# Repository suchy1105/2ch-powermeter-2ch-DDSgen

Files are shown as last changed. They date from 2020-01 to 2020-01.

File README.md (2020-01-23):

# 2ch-powermeter-2ch-DDSgen
2 channel power meter with 2 channel DDS generator with few interfaces 

It is a part of my engeeniering thesis, made in AltiumDesigner, based on STM32F4 reconfigurable with DDS generator AD9851 and logaritmic amplifiler AD8307.

Code(C language) was compile in SystemWorkbench(eclipse), with using CubeMX. The program was upload by STM32CubeProgrammer.
KS

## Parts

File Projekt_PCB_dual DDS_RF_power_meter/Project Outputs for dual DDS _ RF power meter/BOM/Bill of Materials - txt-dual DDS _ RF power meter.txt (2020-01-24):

Comment	Description	Designator	Footprint	LibRef	Manufacturer	Manufacturer Part Number	Manufacturer1 ComponentHeight	Manufacturer1 Example	Manufacturer1 Part Number	Part Description	Part Number	Quantity

"Device"	""	"IC11_U_POWERMES_1, IC11_U_POWERMES_2"	"SOIC127P600X175-8N"	"AD8307AR"	""	""	""	""	""	""	""	"2"
"IRF7389"	""	"Q4, Q5"	"SO-8"	"IRF7389"	""	""	""	""	""	""	""	"2"
"IS42S16"	"SDRAM 64m 200mhz 54tsop"	"IC1"	"TSOP-54"	"IS42S16"	""	""	""	""	""	""	""	"1"
"LAN8742A-CZ-TR"	"LAN8742A-CZ-TR - Small Footprint RMII 10/100 Ethernet, Transceiver with HP Auto-MDIX and flexPWR Technology SQFN-24"	"U2"	"QFN50P400X400X80-25N-S225"	"LAN8742A-CZ-TR"	""	""	""	""	""	""	""	"1"
"LEDRA3010-GYW120"	"LED (Maritex)"	"LED1, LED2, LED3, LED4, LED5"	"LED_KPA3010_G"	"LED_SMD_90deg_G"	""	""	""	""	""	""	""	"5"
"MCP1525T-I/TT"	"2.5 voltage reference"	"IC4"	"SOT95P251X112-3N"	"REF_MCP1525"	""	""	""	""	""	""	""	"1"
"STM809SWX6F"	"2.93V  Reset circuit"	"IC3"	"SOT95P229X119-3N"	"VMON_STM809"	""	""	""	""	""	""	""	"1"
"TC4428A"	"MOSFET Driver"	"IC5, IC6"	"SO-8"	"DRV_TC4428A"	""	""	""	""	""	""	""	"2"
"Header 34"	"Connector 34 Male"	"J3"	"3M_N2534-6002RB"	"3M_N2534-6002RB"	"3M"	"N2534-6002RB"	""	""	""	"34 Contacts - Straight .100'' x .100'' Low Profile Four-Wall Header, 2500 Series"	"3M_N2534-6002RB"	"1"
"32.768KHZ"	"Quartz Crystal"	"Q3"	"XTAL_ABRACON_ABS09"	"XTAL_32.768KHZ_ABRACON_ABS09-32.768KHZ-T"	"ABRACON"	"ABS09-32.768KHZ-T"	""	""	""	"Tolerance: ±20ppm, Stability: ±5ppm, -40°C to +85°C, 12.5pF, SMD Low Profile Crystal, ABS09 Series"	"XTAL_32.768KHZ_ABRACON_ABS09-32.768KHZ-T"	"1"
"MicroUSB-B"	"MicroUSB-B-SMT"	"J5, J7"	"USB-Micro-B-RA-SMD-PiP"	"USB-Micro-B-RA-SMD-PiP"	"Allen Creations Corp."	"AJU55-BS2111-L"	""	""	""	""	"USB-Micro-B-RA-SMD-PiP"	"2"
"AD9851BRSZ"	"CMOS 180MHz DDS/DAC Synthesizer"	"IC10_U_Generator_1, IC10_U_Generator_2"	"SOP65P780X200-28N"	"AD9851BRSZ"	"ANALOG DEVICES"	"AD9851BRSZ"	""	""	""	"CMOS 180MHz DDS/DAC Synthesizer, 10-Bit"	"AD9851BRSZ"	"2"
"AT24C64AN-10SU-1.8"	"64K (8192 x 8), Two-Wire Serial EEPROM"	"IC7"	"SOIC127P600X175-8N"	"AT24C64AN-10SU-1.8"	"ATMEL"	"AT24C64AN-10SU-1.8"	""	""	""	"1.8V, 64K (8192 x 8), Two-Wire Serial EEPROM"	"AT24C64AN-10SU-1.8"	"1"
"microSD"	"Connector MicroSD 8 Pin + Switch"	"J2"	"ATTEND_112A-TAAR-R03"	"ATTEND_112A-TAAR-R03"	"ATTEND"	"112A-TAAR-R03"	""	""	""	"MicroSD Socket, Push-Push Type"	"ATTEND_112A-TAAR-R03"	"1"
"51"	"Resistor - 5%"	"R15, R22, R23, R24"	"RESC6331X80N"	"R2512_51R_5%_2W_200PPM_BOURNS_CRM2512"	"BOURNS"	"CRM2512-JW-510ELF"	""	""	""	"Pulse Resistant Power Thick Film Chip Resistor"	"R2512_51R_5%_2W_200PPM_BOURNS_CRM2512"	"4"
"SMAJ5.0A"	"Transient Voltage Suppressor Diode (Uni-Directional)"	"D3"	"DIOM5226X262N"	"SMAJ5.0A"	"BOURNS"	"SMAJ5.0A"	""	""	""	"Surface Mount Uni-directional Transient Voltage Suppressor Diode"	"SMAJ5.0A"	"1"
"Jack"	"12V /  5A, 2.1mm Diameter Pin, DC Power Socket With  Switch. DC10A Type"	"J6"	"CLIFF_FC68148(DC-10A)"	"CLIFF_FC68148(DC-10A)"	"CLIFF ELECTRONIC COMPONENTS"	"FC68148 (DC-10A)"	""	""	""	"12V/5A, 2.1mm Diameter Pin, DC Power Socket With  Switch (DC10A Type)"	"CLIFF_FC68148(DC-10A)"	"1"
"Switch"	"4 Ways SPST DIP Switch"	"SW1"	"SW_CTS_219-4MST"	"SW_CTS_219-4MST"	"CTS ELECTROCOMPONENTS"	"219-4MST"	""	""	""	"4 Ways, Pitch 2.54mm, SPST DIP Switch, Rating 100mA 50VDC"	"SW_CTS_219-4MST"	"1"
"25MHz"	"Crystal 4 pins 1=XTAL Control 2=GND3=XTAL 4=GND"	"Q1"	"XTAL_EPSON_TSX-3225"	"XTAL_25MHZ_EPSON_TSX-3225 25.0000MF10Z-AC"	"EPSON"	"TSX-3225 25.0000MF10Z-AC"	""	""	""	"Tolerance ±10 ppm,  Stability:± 10ppm, -20°C to 75°C, 9pF, Surface Mount Quartz Crystal, TX-3225 Series"	"XTAL_25MHZ_EPSON_TSX-3225 25.0000MF10Z-AC"	"1"
"BAT54C"	"Dual Common Cathode Schottky Diodes"	"D4, D10"	"SOT95P240X130-3N"	"BAT54C"	"FAIRCHILD SEMICONDUCTOR"	"BAT54C"	""	""	""	"Dual Common Cathode Small Signal Schottky Diode"	"BAT54C"	"2"
"0"	"Resistor"	"R107_U_Generator_1, R107_U_Generator_2, R108_U_Generator_1, R108_U_Generator_2, R110_U_POWERMES_1, R110_U_POWERMES_2"	"RESC1608X55N"	"R0603_0R_JUMPER"	"GENERIC"	"R0603_0R_JUMPER"	"0.55mm"	"NIC COMPONENT"	"NRC06Z0"	"1A (0.05R Max DC Resistance) Zero Ohm Jumper"	"R0603_0R_JUMPER"	"6"
"0"	"Resistor"	"R43, R62, R63, R64"	"RESC1005X40N"	"R0402_0R_JUMPER"	"GENERIC"	"R0402_0R_JUMPER"	"0.4mm"	"YAGEO PHYCOMP"	"232270591001L"	"1A (0.05R Max DC Resistance) Zero Ohm Jumper"	"R0402_0R_JUMPER"	"4"
"100nF"	"Non-polarised capacitor"	"C1, C2, C3, C4, C5, C6, C7, C8, C9, C10, C11, C12, C13, C14, C15, C16, C17, C18, C19, C20, C21, C22, C25, C28, C29, C30, C32, C34, C38, C39, C40, C49, C50, C51, C54, C61, C64, C65, C66, C67"	"CAPC1005X55N"	"CC0402_100NF_16V_10%_X5R"	"GENERIC"	"CC0402_100NF_16V_10%_X5R"	"0.55mm"	"MURATA"	"GRM155R61C104KA88D"	"SMD Multilayer Chip Ceramic Capacitor"	"CC0402_100NF_16V_10%_X5R"	"40"
"100nF"	"Non-polarised capacitor"	"C33, C35"	"CAPC1608X87N"	"CC0603_100NF_50V_10%_X7R"	"GENERIC"	"CC0603_100NF_50V_10%_X7R"	"0.87mm"	"PHYCOMP"	"223858615649"	"SMD Multilayer Chip Ceramic Capacitor"	"CC0603_100NF_50V_10%_X7R"	"2"
"100nF"	"Non-polarised capacitor"	"C59_U_Generator_1, C59_U_Generator_2, C71_U_Generator_1, C71_U_Generator_2, C72_U_Generator_1, C72_U_Generator_2, C73_U_Generator_1, C73_U_Generator_2, C74_U_Generator_1, C74_U_Generator_2, C76_U_POWERMES_1, C76_U_POWERMES_2"	"CAPC0603X33N"	"CC0201_100NF_6.3V_10%_X5R"	"GENERIC"	"CC0201_100NF_6.3V_10%_X5R"	"0.33mm"	"AVX"	"02016D104KAT2A"	"SMD Multilayer Chip Ceramic Capacitor"	"CC0201_100NF_6.3V_10%_X5R"	"12"
"10k"	"Resistor - 1%"	"R16, R17, R18, R19, R20, R21, R25, R28, R29, R30, R31, R32, R33, R34, R35, R36, R44, R47, R48, R49, R50, R51, R57, R58, R59, R93, R94, R95, R96, R100_U_Generator_1, R100_U_Generator_2"	"RESC1005X40N"	"R0402_10K_1%_0.0625W_100PPM"	"GENERIC"	"R0402_10K_1%_0.0625W_100PPM"	"0.4mm"	"YAGEO PHYCOMP"	"232270671003L"	"General Purpose Thick Film Chip Resistor"	"R0402_10K_1%_0.0625W_100PPM"	"31"
"10nF"	"Non-polarised capacitor"	"C58"	"CAPC1005X55N"	"CC0402_10NF_16V_10%_X7R"	"GENERIC"	"CC0402_10NF_16V_10%_X7R"	"0.55mm"	"PHYCOMP"	"223878715636"	"SMD Multilayer Chip Ceramic Capacitor"	"CC0402_10NF_16V_10%_X7R"	"1"
"10uF"	"Non-polarised capacitor"	"C31"	"CAPC2012X135N"	"CC0805_10UF_16V_10%_X5R"	"GENERIC"	"CC0805_10UF_16V_10%_X5R"	"1.4mm"	"KEMET"	"C0805C106K4PAC"	"SMD Multilayer Chip Ceramic Capacitor"	"CC0805_10UF_16V_10%_X5R"	"1"
"10uF"	"Non-polarised capacitor"	"C47, C48"	"CAPC3216X140N"	"CC1206_10UF_16V_10%_X7R"	"GENERIC"	"CC1206_10uF_16V_10%_X7R"	"1.8mm"	"KEMET"	"C1206C106K4RAC"	"SMD Multilayer Chip Ceramic Capacitor"	"CC1206_10UF_16V_10%_X7R"	"2"
"10uF"	"Non-polarised capacitor"	"C75_U_Generator_1, C75_U_Generator_2"	"CAPC1608X80N"	"CC0603_10UF_10V_10%_X5R"	"GENERIC"	"CC0603_10UF_10V_10%_X5R"	"0.8mm"	"MURATA"	"GRM188R61A106KE69D"	"SMD Multilayer Chip Ceramic Capacitor"	"CC0603_10UF_10V_10%_X5R"	"2"
"12pF"	"Non-polarised capacitor"	"C36, C37, C52, C55"	"CAPC1005X55N"	"CC0402_12PF_50V_5%_C0G"	"GENERIC"	"CC0402_12PF_50V_5%_C0G"	"0.55mm"	"KEMET"	"C0402C120J5GACTU"	"SMD Multilayer Chip Ceramic Capacitor"	"CC0402_12PF_50V_5%_C0G"	"4"
"150pF"	"Non-polarised capacitor"	"C46"	"CAPC1005X55N"	"CC0402_150PF_50V_5%_C0G"	"GENERIC"	"CC0402_150PF_50V_5%_C0G"	"0.55mm"	"KEMET"	"C0402C151J5GACTU"	"SMD Multilayer Chip Ceramic Capacitor"	"CC0402_150PF_50V_5%_C0G"	"1"
"18pF"	"Non-polarised capacitor"	"C26, C27"	"CAPC1005X55N"	"CC0402_18PF_50V_5%_C0G"	"GENERIC"	"CC0402_18PF_50V_5%_C0G"	"0.55mm"	"KEMET"	"C0402C180J5GACTU"	"SMD Multilayer Chip Ceramic Capacitor"	"CC0402_18PF_50V_5%_C0G"	"2"
"1k"	"Resistor - 1%"	"R102_U_Generator_1, R102_U_Generator_2, R103_U_Generator_1, R103_U_Generator_2"	"RESC1005X40N"	"R0402_1K_1%_0.0625W_100PPM"	"GENERIC"	"R0402_1K_1%_0.0625W_100PPM"	"0.4mm"	"YAGEO PHYCOMP"	"232270671002L"	"General Purpose Thick Film Chip Resistor"	"R0402_1K_1%_0.0625W_100PPM"	"4"
"1k5"	"Resistor - 1%"	"R5"	"RESC1005X40N"	"R0402_1K5_1%_0.0625W_100PPM"	"GENERIC"	"R0402_1K5_1%_0.0625W_100PPM"	"0.4mm"	"YAGEO PHYCOMP"	"232270671502L"	"General Purpose Thick Film Chip Resistor"	"R0402_1K5_1%_0.0625W_100PPM"	"1"
"1uF"	"Non-polarised capacitor"	"C24, C43"	"CAPC1005X55N"	"CC0402_1UF_16V_10%_X5R"	"GENERIC"	"CC0402_1UF_16V_10%_X5R"	"0.55mm"	"TDK"	"C1005X5R1C105KT"	"SMD Multilayer Chip Ceramic Capacitor"	"CC0402_1UF_16V_10%_X5R"	"2"
"2.2uF"	"Non-polarised capacitor"	"C56, C57"	"CAPC1608X87N"	"CC0603_2.2UF_16V_10%_X5R"	"GENERIC"	"CC0603_2.2UF_16V_10%_X5R"	"0.9mm"	"YAGEO"	"CC0603KRX5R7BB225"	"SMD Multilayer Chip Ceramic Capacitor"	"CC0603_2.2UF_16V_10%_X5R"	"2"
"21k"	"Resistor - 0.1%"	"R12"	"RESC1608X55N"	"R0603_21K_0.1%_0.063W_10PPM"	"GENERIC"	"R0603_21K_0.1%_0.063W_10PPM"	"0.5mm"	"TYCO HOLSWORTHY"	"RN73C1J21KBTDF"	"Thin Film Chip Resistor"	"R0603_21K_0.1%_0.063W_10PPM"	"1"
"220pF"	"Non-polarised capacitor"	"C42_U_POWERMES_1, C42_U_POWERMES_2, C53_U_POWERMES_1, C53_U_POWERMES_2"	"CAPC1005X55N"	"CC0402_220PF_50V_5%_C0G"	"GENERIC"	"CC0402_220PF_50V_5%_C0G"	"0.55mm"	"KEMET"	"C0402C221J5GACTU"	"SMD Multilayer Chip Ceramic Capacitor"	"CC0402_220PF_50V_5%_C0G"	"4"
"22uF"	"Non-polarised capacitor"	"C60, C62, C63"	"CAPC2012X135N"	"CC0805_22UF_16V_10%_X5R"	"GENERIC"	"CC0805_22UF_16V_10%_X5R"	"1.35mm"	"TDK"	"C2012X5R1C226KT"	"SMD Multilayer Chip Ceramic Capacitor"	"CC0805_22UF_16V_10%_X5R"	"3"
"24"	"Resistor - 1%"	"R98_U_Generator_1, R98_U_Generator_2"	"RESC1005X40N"	"R0402_24R_1%_0.0625W_100PPM"	"GENERIC"	"R0402_24R_1%_0.0625W_100PPM"	"0.4mm"	"YAGEO PHYCOMP"	"232270672409L"	"General Purpose Thick Film Chip Resistor"	"R0402_24R_1%_0.0625W_100PPM"	"2"
"24k"	"Resistor - 1%"	"R45"	"RESC1005X40N"	"R0402_24K_1%_0.0625W_100PPM"	"GENERIC"	"R0402_24K_1%_0.0625W_100PPM"	"0.4mm"	"YAGEO PHYCOMP"	"232270672403L"	"General Purpose Thick Film Chip Resistor"	"R0402_24K_1%_0.0625W_100PPM"	"1"
"24k9"	"Resistor - 0.1%"	"R52"	"RESC1608X55N"	"R0603_24K9_0.1%_0.063W_10PPM"	"GENERIC"	"R0603_24K9_0.1%_0.063W_10PPM"	"0.5mm"	"TYCO HOLSWORTHY"	"RN73C1J24K9BTDF"	"Thin Film Chip Resistor"	"R0603_24K9_0.1%_0.063W_10PPM"	"1"
"33"	"Resistor - 1%"	"R10, R11, R13, R97"	"RESC1005X40N"	"R0402_33R_1%_0.0625W_100PPM"	"GENERIC"	"R0402_33R_1%_0.0625W_100PPM"	"0.4mm"	"YAGEO PHYCOMP"	"232270673309L"	"General Purpose Thick Film Chip Resistor"	"R0402_33R_1%_0.0625W_100PPM"	"4"
"3k92"	"Resistor - 0.1%"	"R101_U_Generator_1, R101_U_Generator_2"	"RESC1608X55N"	"R0603_3K92_0.1%_0.063W_10PPM"	"GENERIC"	"R0603_3K92_0.1%_0.063W_10PPM"	"0.5mm"	"TYCO HOLSWORTHY"	"RN73C1J3K92BTDF"	"Thin Film Chip Resistor"	"R0603_3K92_0.1%_0.063W_10PPM"	"2"
"47"	"Resistor - 1%"	"R26, R27, R37, R38, R39, R40, R41, R55, R56, R60, R61, R65, R66, R67, R68, R69, R70, R71, R72, R73, R74, R75, R76, R77, R78, R79, R80, R81, R82, R83, R84, R85, R86, R87, R88, R89, R90, R91, R92"	"RESC1005X40N"	"R0402_47R_1%_0.0625W_100PPM"	"GENERIC"	"R0402_47R_1%_0.0625W_100PPM"	"0.4mm"	"YAGEO PHYCOMP"	"232270674709L"	"General Purpose Thick Film Chip Resistor"	"R0402_47R_1%_0.0625W_100PPM"	"39"
"470pF"	"Non-polarised capacitor"	"C23"	"CAPC1005X55N"	"CC0402_470PF_50V_10%_X7R"	"GENERIC"	"CC0402_470PF_50V_10%_X7R"	"0.55mm"	"PHYCOMP"	"223858715618"	"SMD Multilayer Chip Ceramic Capacitor"	"CC0402_470PF_50V_10%_X7R"	"1"
"47k"	"Resistor - 1%"	"R46"	"RESC1005X40N"	"R0402_47K_1%_0.0625W_100PPM"	"GENERIC"	"R0402_47K_1%_0.0625W_100PPM"	"0.4mm"	"YAGEO PHYCOMP"	"232270675103L"	"General Purpose Thick Film Chip Resistor"	"R0402_47K_1%_0.0625W_100PPM"	"1"
"49R9"	"Resistor - 0.1%"	"R1, R2, R3, R4"	"RESC1005X35N"	"R0402_49R9_0.1%_0.063W_25PPM"	"GENERIC"	"R0402_49R9_0.1%_0.063W_25PPM"	"0.35mm"	"TE CONNECTIVITY"	"CPF0402B49R9E1"	"Thin Film Precision Resistor"	"R0402_49R9_0.1%_0.063W_25PPM"	"4"
"49R9"	"Resistor - 1%"	"R42, R99_U_Generator_1, R99_U_Generator_2"	"RESC1005X40N"	"R0402_49R9_1%_0.0625W_100PPM"	"GENERIC"	"R0402_49R9_1%_0.0625W_100PPM"	"0.4mm"	"YAGEO PHYCOMP"	"232270674999L or RC0402FR-0749R9L"	"General Purpose Thick Film Chip Resistor"	"R0402_49R9_1%_0.0625W_100PPM"	"3"
"4k7"	"Resistor - 1%"	"R6, R7, R8, R9, R14"	"RESC1005X40N"	"R0402_4K7_1%_0.0625W_100PPM"	"GENERIC"	"R0402_4K7_1%_0.0625W_100PPM"	"0.4mm"	"YAGEO PHYCOMP"	"232270674702L"	"General Purpose Thick Film Chip Resistor"	"R0402_4K7_1%_0.0625W_100PPM"	"5"
"4k99"	"Resistor - 1%"	"R54"	"RESC1608X55N"	"R0603_4K99_1%_0.063W_50PPM"	"GENERIC"	"R0603_4K99_1%_0.063W_50PPM"	"0.55mm"	"TYCO NEOHM"	"CPF0603F4K99C1"	"General Purpose Thick Film Chip Resistor"	"R0603_4K99_1%_0.063W_50PPM"	"1"
"4R7"	"Resistor - 1%"	"R109_U_POWERMES_1, R109_U_POWERMES_2"	"RESC1005X40N"	"R0402_4R7_1%_0.0625W_200PPM"	"GENERIC"	"R0402_4R7_1%_0.0625W_200PPM"	"0.4mm"	"YAGEO PHYCOMP"	"232270674708L"	"General Purpose Thick Film Chip Resistor"	"R0402_4R7_1%_0.0625W_200PPM"	"2"
"50"	"Resistor - 0.1%"	"R105, R106"	"RESC1005X35N"	"R0402_50R_0.1%_0.05W_25PPM"	"GENERIC"	"R0402_50R_0.1%_0.05W_25PPM"	"0.38mm"	"VISHAY DALE"	"FC0402E50R0BTBS"	"Thin Film Precision Resistor"	"R0402_50R_0.1%_0.05W_25PPM"	"2"
"51"	"Resistor - 1%"	"R104_U_POWERMES_1, R104_U_POWERMES_2"	"RESC1005X40N"	"R0402_51R_1%_0.0625W_100PPM"	"GENERIC"	"R0402_51R_1%_0.0625W_100PPM"	"0.4mm"	"YAGEO PHYCOMP"	"232270675109L"	"General Purpose Thick Film Chip Resistor"	"R0402_51R_1%_0.0625W_100PPM"	"2"
"6.8nF"	"Non-polarised capacitor"	"C68"	"CAPC1608X87N"	"CC0603_6.8NF_50V_5%_X7R"	"GENERIC"	"CC0603_6.8NF_50V_5%_X7R"	"0.87mm"	"PHYCOMP"	"223858615634"	"SMD Multilayer Chip Ceramic Capacitor"	"CC0603_6.8NF_50V_5%_X7R"	"1"
"7k87"	"Resistor - 0.1%"	"R53"	"RESC1608X55N"	"R0603_7K87_0.1%_0.063W_10PPM"	"GENERIC"	"R0603_7K87_0.1%_0.063W_10PPM"	"0.5mm"	"TYCO HOLSWORTHY"	"RN73C1J7K87BTDF"	"Thin Film Chip Resistor"	"R0603_7K87_0.1%_0.063W_10PPM"	"1"
"SMA"	""	"J4, J8_U_Generator_1, J8_U_Generator_2, J9_U_POWERMES_1, J9_U_POWERMES_2"	"HUBER-SUHNER_85_SMA-50-0-101/111_NE"	"HUBER-SUHNER_85_SMA-50-0-101/111_NE"	"HUBER+SUHNER"	"85_SMA-50-0-101/111_NE"	""	""	""	"SMA 50 Ohms Right Angle PCB Jack"	"HUBER-SUHNER_85_SMA-50-0-101/111_NE"	"5"
"Value"	"Battery Holder whit 2 Pin"	"BATH1"	"BATH_KEYSTONE_2998"	"BATH_KEYSTONE_2998"	"KEYSTONE"	"2998"	""	""	""	"SMD Battery Holder for SR60, SR66, SR621, LR621, MC621, V364, SC621, DR13H, D377, V13AT Buttun Cell Battery"	"BATH_KEYSTONE_2998"	"1"
"25MHz"	"Oscillator 4 pins 1=\ST 2=GND 3=OUT 4=VCC"	"OSC1"	"OSC_MICREL_2520"	"OSC_25MHZ_MICREL_DSC1001DI5-025.0000T"	"MICREL"	"DSC1001DI5-025.0000T"	""	""	""	"1.8V-3.3V, ±10ppm, 15pF,-40..85°C, HCMOS/TTL Surface Mount Low-Power Precision CMOS Oscillator (DSC1001 Series)"	"OSC_25MHZ_MICREL_DSC1001DI5-025.0000T"	"1"
"220R@100MHz"	"Inductor"	"FB1, FB2, FB3, L2"	"INDC2012X105N"	"IND0805_MURATA_BLM21PG221SN1D"	"MURATA"	"BLM21PG221SN1D"	""	""	""	"SMD EMIFIL Suppression Chip Ferrite Bead"	"IND0805_MURATA_BLM21PG221SN1D"	"4"
"90R@100MHz"	"Inductor Common Mode"	"L1, L6"	"IND_MURATA_DLW21S"	"IND_MURATA_DLW21SN900SQ2L"	"MURATA"	"DLW21SN900SQ2L"	""	""	""	"Wire Wound Common Mode Choke Coil (DLW21S Series)"	"IND_MURATA_DLW21SN900SQ2L"	"2"
"74AHC1G04GW"	"Single Inverter Buffer"	"IC8, IC9"	"SOT65P212X110-5N"	"74AHC1G04GW"	"NXP SEMICONDUCTORS"	"74AHC1G04GW"	""	""	""	"Single Inverter Buffer"	"74AHC1G04GW"	"2"
"PRTR5V0U2X"	"Ultra Low Capacitance Double Rail-to-Rail ESD Protection Diode"	"D1, D2, D6, D11"	"SOT190P230X110-4N"	"PRTR5V0U2X"	"NXP SEMICONDUCTORS"	"PRTR5V0U2X"	""	""	""	"Ultra Low Capacitance (1pF) Double Rail-to-Rail ESD Protection Diode (8kV)"	"PRTR5V0U2X"	"4"
"NCP3170ADR2G"	"Synchronous PWM Switching Converter"	"IC2"	"SOIC127P600X175-8N"	"NCP3170ADR2G"	"ON SEMICONDUCTOR"	"NCP3170ADR2G"	""	""	""	"Synchronous PWM Switching Converter"	"NCP3170ADR2G"	"1"
""	"LED Green 1C 2A"	"LD10, LD11, LD12"	"LED_OSRAM_LGL29K"	"LED_OSRAM_LG L29K-G2J1-24-Z"	"OSRAM"	"LG L29K-G2J1-24-Z"	""	""	""	"Surface Mount Green LED (0603 Case)"	"LED_OSRAM_LG L29K-G2J1-24-Z"	"3"
"100uF"	"Polarised capacitor"	"C41"	"CAPAE660X540N"	"CAE660-540_100UF_16V_20%"	"PANASONIC"	"EEEFK1C101AP"	""	""	""	"Aluminum Electrolytic SMT Capacitor"	"CAE660-540_100UF_16V_20%"	"1"
"CP2102-GM"	"Single-Chip USB to UART Bridge, 1024 Bytes EEPROM, -40 to 85 degC, 28-pin QFN, Tube"	"U4"	"SLAB-QFN-28-3125x3125TP_N"	"CP2102-GM"	"Silicon Labs"	""	""	""	""	""	""	"1"
"STM32F429IIT6"	"ARM Cortex-M4 32-bit MCU+FPU, 225 DMIPS, 2048 kB Flash, 256 kB Internal RAM, 140 I/Os, 176-pin LQFP, -40 to 85 degC, Tray"	"U1"	"STM-LQFP176_N"	"STM32F429IIT6"	"STMicroelectronics"	""	""	""	""	""	""	"1"
"8MHz"	"Quartz Crystal"	"Q2"	"XTAL_TXC_7A"	"XTAL_8MHZ_TXC_7A-8.000MAAE-T"	"TXC CORPORATION"	"7A-8.000MAAE-T"	""	""	""	"Tolerance: ±30ppm, Stability: ±30ppm, -20°C to +70°C, 12pF, SMD Glass Seam Sealing Crystal, 7A Series"	"XTAL_8MHZ_TXC_7A-8.000MAAE-T"	"1"
"1.5A-6V"	"Fuse"	"F1"	"FUSRC4632X90N"	"FUSR1812_TYCO-MINISMDC150F-2"	"TYCO ELECTRONICS"	"miniSMDC150F-2"	""	""	""	"PolySwitch® PTC Overcurrent Protection Device"	"FUSR1812_TYCO-MINISMDC150F-2"	"1"
"Push Button"	"Push-Button Switch SPDT"	"PB2"	"PB_TYCO_FSMSM"	"PB_TYCO_FSMSM"	"TYCO ELECTRONICS"	"FSMSM or 1437566-3"	""	""	""	"12VDC 50mA SPST Tactile  Push-Button Switch"	"PB_TYCO_FSMSM"	"1"
"RJ45"	"1 Port, Yellow/Green LEDs, RJ45 10/100Base-T Ethernet, Mag45 Connector Module With Integrated Magnetics"	"J1"	"TYCO_5-6605308-1"	"TYCO_5-6605308-1"	"TYCO ELECTRONICS"	"5-6605308-1"	""	""	""	"1 Port, Yellow/Green LEDs, RJ45 10/100Base-T Ethernet, Mag45 Connector Module With Integrated Magnetics"	"TYCO_5-6605308-1"	"1"
"Undefined"	"Non-polarised capacitor"	"C44, C45"	"CAPC2012X135N"	"CC0805_NO-VALUE"	"Undefined"	"CC0805_NO-VALUE"	"1.35mm"	""	""	"Reserved Footprint For 0805(2012) Chip Ceramic Capacitor"	"CC0805_NO-VALUE"	"2"
"Undefined"	"Non-polarised capacitor"	"C69_U_Generator_1, C69_U_Generator_2, C70_U_Generator_1, C70_U_Generator_2"	"CAPC1608X90N"	"CC0603_NO-VALUE"	"Undefined"	"CC0603_NO-VALUE"	"0.9mm"	""	""	"Reserved Footprint For 0603(1608) Chip Ceramic Capacitor"	"CC0603_NO-VALUE"	"4"
"4.7uH"	"Inductor With Core"	"L7"	"INDM5552X200N"	"IND2020_4.7UH_20%_VISHAY_IHLP-2020BZ-11"	"VISHAY DALE"	"IHLP2020BZER4R7M11"	""	""	""	"Low Profile, High Current IHLP® Inductor"	"IND2020_4.7UH_20%_VISHAY_IHLP-2020BZ-11"	"1"
"SS16"	"Schottky Diode"	"D5, D7, D8, D9, D12"	"DIOM5127X229N"	"SS16"	"VISHAY GENERAL SEMICONDUCTOR"	"SS16"	""	""	""	"Surface Mount Schottky Barrier Rectifier"	"SS16"	"5"
"Pin Header 2x5, 1.27mm"	"Pin Header 2x5, 1.27mm (50mil), SMD, Keying Shroud"	"P2"	"HDR_2x5-SMD-1.27mm-K"	"Pin Header 2x5 SMD, 1.27mm, KS"	"WCON"	"3132-10MS0BK00R1"	""	""	""	""	"Pin Header 2x5 SMD, 1.27mm, KS"	"1"

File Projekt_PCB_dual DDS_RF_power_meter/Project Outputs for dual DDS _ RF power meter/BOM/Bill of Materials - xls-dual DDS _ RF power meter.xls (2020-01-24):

Quantity | Designator | Manufacturer | Manufacturer Part Number | Manufacturer1 Example | Manufacturer1 Part Number | Comment | Description | Part Description | Footprint | LibRef
1.0 | BATH1 | KEYSTONE | 2998 |  |  | Value | Battery Holder whit 2 Pin | SMD Battery Holder for SR60, SR66, SR621, LR621, MC621, V364, SC621, DR13H, D377, V13AT Buttun Cell Battery | BATH_KEYSTONE_2998 | BATH_KEYSTONE_2998
1.0 | C41 | PANASONIC | EEEFK1C101AP |  |  | 100uF | Polarised capacitor | Aluminum Electrolytic SMT Capacitor | CAPAE660X540N | CAE660-540_100UF_16V_20%
1.0 | D3 | BOURNS | SMAJ5.0A |  |  | SMAJ5.0A | Transient Voltage Suppressor Diode (Uni-Directional) | Surface Mount Uni-directional Transient Voltage Suppressor Diode | DIOM5226X262N | SMAJ5.0A
1.0 | F1 | TYCO ELECTRONICS | miniSMDC150F-2 |  |  | 1.5A-6V | Fuse | PolySwitch® PTC Overcurrent Protection Device | FUSRC4632X90N | FUSR1812_TYCO-MINISMDC150F-2
1.0 | IC1 |  |  |  |  | IS42S16 | SDRAM 64m 200mhz 54tsop |  | TSOP-54 | IS42S16
1.0 | IC2 | ON SEMICONDUCTOR | NCP3170ADR2G |  |  | NCP3170ADR2G | Synchronous PWM Switching Converter | Synchronous PWM Switching Converter | SOIC127P600X175-8N | NCP3170ADR2G
1.0 | IC3 |  |  |  |  | STM809SWX6F | 2.93V Reset circuit |  | SOT95P229X119-3N | VMON_STM809
1.0 | IC4 |  |  |  |  | MCP1525T-I/TT | 2.5 voltage reference |  | SOT95P251X112-3N | REF_MCP1525
1.0 | IC7 | ATMEL | AT24C64AN-10SU-1.8 |  |  | AT24C64AN-10SU-1.8 | 64K (8192 x 8), Two-Wire Serial EEPROM | 1.8V, 64K (8192 x 8), Two-Wire Serial EEPROM | SOIC127P600X175-8N | AT24C64AN-10SU-1.8
1.0 | J1 | TYCO ELECTRONICS | 5-6605308-1 |  |  | RJ45 | 1 Port, Yellow/Green LEDs, RJ45 10/100Base-T Ethernet, Mag45 Connector Module With Integrated Magnetics | 1 Port, Yellow/Green LEDs, RJ45 10/100Base-T Ethernet, Mag45 Connector Module With Integrated Magnetics | TYCO_5-6605308-1 | TYCO_5-6605308-1
1.0 | J2 | ATTEND | 112A-TAAR-R03 |  |  | microSD | Connector MicroSD 8 Pin + Switch | MicroSD Socket, Push-Push Type | ATTEND_112A-TAAR-R03 | ATTEND_112A-TAAR-R03
1.0 | J3 | 3M | N2534-6002RB |  |  | Header 34 | Connector 34 Male | 34 Contacts - Straight .100'' x .100'' Low Profile Four-Wall Header, 2500 Series | 3M_N2534-6002RB | 3M_N2534-6002RB
1.0 | J6 | CLIFF ELECTRONIC COMPONENTS | FC68148 (DC-10A) |  |  | Jack | 12V / 5A, 2.1mm Diameter Pin, DC Power Socket With Switch. DC10A Type | 12V/5A, 2.1mm Diameter Pin, DC Power Socket With Switch (DC10A Type) | CLIFF_FC68148(DC-10A) | CLIFF_FC68148(DC-10A)
1.0 | L7 | VISHAY DALE | IHLP2020BZER4R7M11 |  |  | 4.7uH | Inductor With Core | Low Profile, High Current IHLP® Inductor | INDM5552X200N | IND2020_4.7UH_20%_VISHAY_IHLP-2020BZ-11
1.0 | OSC1 | MICREL | DSC1001DI5-025.0000T |  |  | 25MHz | Oscillator 4 pins 1=\ST 2=GND 3=OUT 4=VCC | 1.8V-3.3V, ±10ppm, 15pF,-40..85°C, HCMOS/TTL Surface Mount Low-Power Precision CMOS Oscillator (DSC1001 Series) | OSC_MICREL_2520 | OSC_25MHZ_MICREL_DSC1001DI5-025.0000T
1.0 | P2 | WCON | 3132-10MS0BK00R1 |  |  | Pin Header 2x5, 1.27mm | Pin Header 2x5, 1.27mm (50mil), SMD, Keying Shroud |  | HDR_2x5-SMD-1.27mm-K | Pin Header 2x5 SMD, 1.27mm, KS
1.0 | PB2 | TYCO ELECTRONICS | FSMSM or 1437566-3 |  |  | Push Button | Push-Button Switch SPDT | 12VDC 50mA SPST Tactile Push-Button Switch | PB_TYCO_FSMSM | PB_TYCO_FSMSM
1.0 | Q1 | EPSON | TSX-3225 25.0000MF10Z-AC |  |  | 25MHz | Crystal 4 pins 1=XTAL Control 2=GND3=XTAL 4=GND | Tolerance ±10 ppm, Stability:± 10ppm, -20°C to 75°C, 9pF, Surface Mount Quartz Crystal, TX-3225 Series | XTAL_EPSON_TSX-3225 | XTAL_25MHZ_EPSON_TSX-3225 25.0000MF10Z-AC
1.0 | Q2 | TXC CORPORATION | 7A-8.000MAAE-T |  |  | 8MHz | Quartz Crystal | Tolerance: ±30ppm, Stability: ±30ppm, -20°C to +70°C, 12pF, SMD Glass Seam Sealing Crystal, 7A Series | XTAL_TXC_7A | XTAL_8MHZ_TXC_7A-8.000MAAE-T
1.0 | Q3 | ABRACON | ABS09-32.768KHZ-T |  |  | 32.768KHZ | Quartz Crystal | Tolerance: ±20ppm, Stability: ±5ppm, -40°C to +85°C, 12.5pF, SMD Low Profile Crystal, ABS09 Series | XTAL_ABRACON_ABS09 | XTAL_32.768KHZ_ABRACON_ABS09-32.768KHZ-T
1.0 | SW1 | CTS ELECTROCOMPONENTS | 219-4MST |  |  | Switch | 4 Ways SPST DIP Switch | 4 Ways, Pitch 2.54mm, SPST DIP Switch, Rating 100mA 50VDC | SW_CTS_219-4MST | SW_CTS_219-4MST
1.0 | U1 | STMicroelectronics |  |  |  | STM32F429IIT6 | ARM Cortex-M4 32-bit MCU+FPU, 225 DMIPS, 2048 kB Flash, 256 kB Internal RAM, 140 I/Os, 176-pin LQFP, -40 to 85 degC, Tray |  | STM-LQFP176_N | STM32F429IIT6
1.0 | U2 |  |  |  |  | LAN8742A-CZ-TR | LAN8742A-CZ-TR - Small Footprint RMII 10/100 Ethernet, Transceiver with HP Auto-MDIX and flexPWR Technology SQFN-24 |  | QFN50P400X400X80-25N-S225 | LAN8742A-CZ-TR
1.0 | U4 | Silicon Labs |  |  |  | CP2102-GM | Single-Chip USB to UART Bridge, 1024 Bytes EEPROM, -40 to 85 degC, 28-pin QFN, Tube |  | SLAB-QFN-28-3125x3125TP_N | CP2102-GM
2.0 | C44, C45 | Undefined | CC0805_NO-VALUE |  |  | Undefined | Non-polarised capacitor | Reserved Footprint For 0805(2012) Chip Ceramic Capacitor | CAPC2012X135N | CC0805_NO-VALUE
2.0 | D4, D10 | FAIRCHILD SEMICONDUCTOR | BAT54C |  |  | BAT54C | Dual Common Cathode Schottky Diodes | Dual Common Cathode Small Signal Schottky Diode | SOT95P240X130-3N | BAT54C
2.0 | IC10_U_Generator_1, IC10_U_Generator_2 | ANALOG DEVICES | AD9851BRSZ |  |  | AD9851BRSZ | CMOS 180MHz DDS/DAC Synthesizer | CMOS 180MHz DDS/DAC Synthesizer, 10-Bit | SOP65P780X200-28N | AD9851BRSZ
2.0 | IC11_U_POWERMES_1, IC11_U_POWERMES_2 |  |  |  |  | Device |  |  | SOIC127P600X175-8N | AD8307AR
2.0 | IC5, IC6 |  |  |  |  | TC4428A | MOSFET Driver |  | SO-8 | DRV_TC4428A
2.0 | IC8, IC9 | NXP SEMICONDUCTORS | 74AHC1G04GW |  |  | 74AHC1G04GW | Single Inverter Buffer | Single Inverter Buffer | SOT65P212X110-5N | 74AHC1G04GW
2.0 | J5, J7 | Allen Creations Corp. | AJU55-BS2111-L |  |  | MicroUSB-B | MicroUSB-B-SMT |  | USB-Micro-B-RA-SMD-PiP | USB-Micro-B-RA-SMD-PiP
2.0 | L1, L6 | MURATA | DLW21SN900SQ2L |  |  | 90R@100MHz | Inductor Common Mode | Wire Wound Common Mode Choke Coil (DLW21S Series) | IND_MURATA_DLW21S | IND_MURATA_DLW21SN900SQ2L
2.0 | Q4, Q5 |  |  |  |  | IRF7389 |  |  | SO-8 | IRF7389
3.0 | LD10, LD11, LD12 | OSRAM | LG L29K-G2J1-24-Z |  |  |  | LED Green 1C 2A | Surface Mount Green LED (0603 Case) | LED_OSRAM_LGL29K | LED_OSRAM_LG L29K-G2J1-24-Z
4.0 | C69_U_Generator_1, C69_U_Generator_2, C70_U_Generator_1, C70_U_Generator_2 | Undefined | CC0603_NO-VALUE |  |  | Undefined | Non-polarised capacitor | Reserved Footprint For 0603(1608) Chip Ceramic Capacitor | CAPC1608X90N | CC0603_NO-VALUE
4.0 | D1, D2, D6, D11 | NXP SEMICONDUCTORS | PRTR5V0U2X |  |  | PRTR5V0U2X | Ultra Low Capacitance Double Rail-to-Rail ESD Protection Diode | Ultra Low Capacitance (1pF) Double Rail-to-Rail ESD Protection Diode (8kV) | SOT190P230X110-4N | PRTR5V0U2X
4.0 | FB1, FB2, FB3, L2 | MURATA | BLM21PG221SN1D |  |  | 220R@100MHz | Inductor | SMD EMIFIL Suppression Chip Ferrite Bead | INDC2012X105N | IND0805_MURATA_BLM21PG221SN1D
4.0 | R15, R22, R23, R24 | BOURNS | CRM2512-JW-510ELF |  |  | 51 | Resistor - 5% | Pulse Resistant Power Thick Film Chip Resistor | RESC6331X80N | R2512_51R_5%_2W_200PPM_BOURNS_CRM2512
5.0 | D5, D7, D8, D9, D12 | VISHAY GENERAL SEMICONDUCTOR | SS16 |  |  | SS16 | Schottky Diode | Surface Mount Schottky Barrier Rectifier | DIOM5127X229N | SS16
5.0 | J4, J8_U_Generator_1, J8_U_Generator_2, J9_U_POWERMES_1, J9_U_POWERMES_2 | HUBER+SUHNER | 85_SMA-50-0-101/111_NE |  |  | SMA |  | SMA 50 Ohms Right Angle PCB Jack | HUBER-SUHNER_85_SMA-50-0-101/111_NE | HUBER-SUHNER_85_SMA-50-0-101/111_NE
5.0 | LED1, LED2, LED3, LED4, LED5 |  |  |  |  | LEDRA3010-GYW120 | LED (Maritex) |  | LED_KPA3010_G | LED_SMD_90deg_G
12.0 | C59_U_Generator_1, C59_U_Generator_2, C71_U_Generator_1, C71_U_Generator_2, C72_U_Generator_1, C72_U_Generator_2, C73_U_Generator_1, C73_U_Generator_2, C74_U_Generator_1, C74_U_Generator_2, C76_U_POWERMES_1, C76_U_POWERMES_2 | GENERIC | CC0201_100NF_6.3V_10%_X5R | AVX | 02016D104KAT2A | 100nF | Non-polarised capacitor | SMD Multilayer Chip Ceramic Capacitor | CAPC0603X33N | CC0201_100NF_6.3V_10%_X5R
1.0 | C68 | GENERIC | CC0603_6.8NF_50V_5%_X7R | PHYCOMP | 223858615634 | 6.8nF | Non-polarised capacitor | SMD Multilayer Chip Ceramic Capacitor | CAPC1608X87N | CC0603_6.8NF_50V_5%_X7R
2.0 | C33, C35 | GENERIC | CC0603_100NF_50V_10%_X7R | PHYCOMP | 223858615649 | 100nF | Non-polarised capacitor | SMD Multilayer Chip Ceramic Capacitor | CAPC1608X87N | CC0603_100NF_50V_10%_X7R
1.0 | C23 | GENERIC | CC0402_470PF_50V_10%_X7R | PHYCOMP | 223858715618 | 470pF | Non-polarised capacitor | SMD Multilayer Chip Ceramic Capacitor | CAPC1005X55N | CC0402_470PF_50V_10%_X7R
1.0 | C58 | GENERIC | CC0402_10NF_16V_10%_X7R | PHYCOMP | 223878715636 | 10nF | Non-polarised capacitor | SMD Multilayer Chip Ceramic Capacitor | CAPC1005X55N | CC0402_10NF_16V_10%_X7R
4.0 | R43, R62, R63, R64 | GENERIC | R0402_0R_JUMPER | YAGEO PHYCOMP | 232270591001L | 0 | Resistor | 1A (0.05R Max DC Resistance) Zero Ohm Jumper | RESC1005X40N | R0402_0R_JUMPER
4.0 | R102_U_Generator_1, R102_U_Generator_2, R103_U_Generator_1, R103_U_Generator_2 | GENERIC | R0402_1K_1%_0.0625W_100PPM | YAGEO PHYCOMP | 232270671002L | 1k | Resistor - 1% | General Purpose Thick Film Chip Resistor | RESC1005X40N | R0402_1K_1%_0.0625W_100PPM
31.0 | R16, R17, R18, R19, R20, R21, R25, R28, R29, R30, R31, R32, R33, R34, R35, R36, R44, R47, R48, R49, R50, R51, R57, R58, R59, R93, R94, R95, R96, R100_U_Generator_1, R100_U_Generator_2 | GENERIC | R0402_10K_1%_0.0625W_100PPM | YAGEO PHYCOMP | 232270671003L | 10k | Resistor - 1% | General Purpose Thick Film Chip Resistor | RESC1005X40N | R0402_10K_1%_0.0625W_100PPM
1.0 | R5 | GENERIC | R0402_1K5_1%_0.0625W_100PPM | YAGEO PHYCOMP | 232270671502L | 1k5 | Resistor - 1% | General Purpose Thick Film Chip Resistor | RESC1005X40N | R0402_1K5_1%_0.0625W_100PPM
1.0 | R45 | GENERIC | R0402_24K_1%_0.0625W_100PPM | YAGEO PHYCOMP | 232270672403L | 24k | Resistor - 1% | General Purpose Thick Film Chip Resistor | RESC1005X40N | R0402_24K_1%_0.0625W_100PPM
2.0 | R98_U_Generator_1, R98_U_Generator_2 | GENERIC | R0402_24R_1%_0.0625W_100PPM | YAGEO PHYCOMP | 232270672409L | 24 | Resistor - 1% | General Purpose Thick Film Chip Resistor | RESC1005X40N | R0402_24R_1%_0.0625W_100PPM
4.0 | R10, R11, R13, R97 | GENERIC | R0402_33R_1%_0.0625W_100PPM | YAGEO PHYCOMP | 232270673309L | 33 | Resistor - 1% | General Purpose Thick Film Chip Resistor | RESC1005X40N | R0402_33R_1%_0.0625W_100PPM
5.0 | R6, R7, R8, R9, R14 | GENERIC | R0402_4K7_1%_0.0625W_100PPM | YAGEO PHYCOMP | 232270674702L | 4k7 | Resistor - 1% | General Purpose Thick Film Chip Resistor | RESC1005X40N | R0402_4K7_1%_0.0625W_100PPM
2.0 | R109_U_POWERMES_1, R109_U_POWERMES_2 | GENERIC | R0402_4R7_1%_0.0625W_200PPM | YAGEO PHYCOMP | 232270674708L | 4R7 | Resistor - 1% | General Purpose Thick Film Chip Resistor | RESC1005X40N | R0402_4R7_1%_0.0625W_200PPM
39.0 | R26, R27, R37, R38, R39, R40, R41, R55, R56, R60, R61, R65, R66, R67, R68, R69, R70, R71, R72, R73, R74, R75, R76, R77, R78, R79, R80, R81, R82, R83, R84, R85, R86, R87, R88, R89, R90, R91, R92 | GENERIC | R0402_47R_1%_0.0625W_100PPM | YAGEO PHYCOMP | 232270674709L | 47 | Resistor - 1% | General Purpose Thick Film Chip Resistor | RESC1005X40N | R0402_47R_1%_0.0625W_100PPM
3.0 | R42, R99_U_Generator_1, R99_U_Generator_2 | GENERIC | R0402_49R9_1%_0.0625W_100PPM | YAGEO PHYCOMP | 232270674999L or RC0402FR-0749R9L | 49R9 | Resistor - 1% | General Purpose Thick Film Chip Resistor | RESC1005X40N | R0402_49R9_1%_0.0625W_100PPM
1.0 | R46 | GENERIC | R0402_47K_1%_0.0625W_100PPM | YAGEO PHYCOMP | 232270675103L | 47k | Resistor - 1% | General Purpose Thick Film Chip Resistor | RESC1005X40N | R0402_47K_1%_0.0625W_100PPM
2.0 | R104_U_POWERMES_1, R104_U_POWERMES_2 | GENERIC | R0402_51R_1%_0.0625W_100PPM | YAGEO PHYCOMP | 232270675109L | 51 | Resistor - 1% | General Purpose Thick Film Chip Resistor | RESC1005X40N | R0402_51R_1%_0.0625W_100PPM
4.0 | C36, C37, C52, C55 | GENERIC | CC0402_12PF_50V_5%_C0G | KEMET | C0402C120J5GACTU | 12pF | Non-polarised capacitor | SMD Multilayer Chip Ceramic Capacitor | CAPC1005X55N | CC0402_12PF_50V_5%_C0G
1.0 | C46 | GENERIC | CC0402_150PF_50V_5%_C0G | KEMET | C0402C151J5GACTU | 150pF | Non-polarised capacitor | SMD Multilayer Chip Ceramic Capacitor | CAPC1005X55N | CC0402_150PF_50V_5%_C0G
2.0 | C26, C27 | GENERIC | CC0402_18PF_50V_5%_C0G | KEMET | C0402C180J5GACTU | 18pF | Non-polarised capacitor | SMD Multilayer Chip Ceramic Capacitor | CAPC1005X55N | CC0402_18PF_50V_5%_C0G
4.0 | C42_U_POWERMES_1, C42_U_POWERMES_2, C53_U_POWERMES_1, C53_U_POWERMES_2 | GENERIC | CC0402_220PF_50V_5%_C0G | KEMET | C0402C221J5GACTU | 220pF | Non-polarised capacitor | SMD Multilayer Chip Ceramic Capacitor | CAPC1005X55N | CC0402_220PF_50V_5%_C0G
1.0 | C31 | GENERIC | CC0805_10UF_16V_10%_X5R | KEMET | C0805C106K4PAC | 10uF | Non-polarised capacitor | SMD Multilayer Chip Ceramic Capacitor | CAPC2012X135N | CC0805_10UF_16V_10%_X5R
2.0 | C24, C43 | GENERIC | CC0402_1UF_16V_10%_X5R | TDK | C1005X5R1C105KT | 1uF | Non-polarised capacitor | SMD Multilayer Chip Ceramic Capacitor | CAPC1005X55N | CC0402_1UF_16V_10%_X5R
2.0 | C47, C48 | GENERIC | CC1206_10uF_16V_10%_X7R | KEMET | C1206C106K4RAC | 10uF | Non-polarised capacitor | SMD Multilayer Chip Ceramic Capacitor | CAPC3216X140N | CC1206_10UF_16V_10%_X7R
3.0 | C60, C62, C63 | GENERIC | CC0805_22UF_16V_10%_X5R | TDK | C2012X5R1C226KT | 22uF | Non-polarised capacitor | SMD Multilayer Chip Ceramic Capacitor | CAPC2012X135N | CC0805_22UF_16V_10%_X5R
2.0 | C56, C57 | GENERIC | CC0603_2.2UF_16V_10%_X5R | YAGEO | CC0603KRX5R7BB225 | 2.2uF | Non-polarised capacitor | SMD Multilayer Chip Ceramic Capacitor | CAPC1608X87N | CC0603_2.2UF_16V_10%_X5R
4.0 | R1, R2, R3, R4 | GENERIC | R0402_49R9_0.1%_0.063W_25PPM | TE CONNECTIVITY | CPF0402B49R9E1 | 49R9 | Resistor - 0.1% | Thin Film Precision Resistor | RESC1005X35N | R0402_49R9_0.1%_0.063W_25PPM
1.0 | R54 | GENERIC | R0603_4K99_1%_0.063W_50PPM | TYCO NEOHM | CPF0603F4K99C1 | 4k99 | Resistor - 1% | General Purpose Thick Film Chip Resistor | RESC1608X55N | R0603_4K99_1%_0.063W_50PPM
2.0 | R105, R106 | GENERIC | R0402_50R_0.1%_0.05W_25PPM | VISHAY DALE | FC0402E50R0BTBS | 50 | Resistor - 0.1% | Thin Film Precision Resistor | RESC1005X35N | R0402_50R_0.1%_0.05W_25PPM
40.0 | C1, C2, C3, C4, C5, C6, C7, C8, C9, C10, C11, C12, C13, C14, C15, C16, C17, C18, C19, C20, C21, C22, C25, C28, C29, C30, C32, C34, C38, C39, C40, C49, C50, C51, C54, C61, C64, C65, C66, C67 | GENERIC | CC0402_100NF_16V_10%_X5R | MURATA | GRM155R61C104KA88D | 100nF | Non-polarised capacitor | SMD Multilayer Chip Ceramic Capacitor | CAPC1005X55N | CC0402_100NF_16V_10%_X5R
2.0 | C75_U_Generator_1, C75_U_Generator_2 | GENERIC | CC0603_10UF_10V_10%_X5R | MURATA | GRM188R61A106KE69D | 10uF | Non-polarised capacitor | SMD Multilayer Chip Ceramic Capacitor | CAPC1608X80N | CC0603_10UF_10V_10%_X5R
6.0 | R107_U_Generator_1, R107_U_Generator_2, R108_U_Generator_1, R108_U_Generator_2, R110_U_POWERMES_1, R110_U_POWERMES_2 | GENERIC | R0603_0R_JUMPER | NIC COMPONENT | NRC06Z0 | 0 | Resistor | 1A (0.05R Max DC Resistance) Zero Ohm Jumper | RESC1608X55N | R0603_0R_JUMPER
2.0 | R101_U_Generator_1, R101_U_Generator_2 | GENERIC | R0603_3K92_0.1%_0.063W_10PPM | TYCO HOLSWORTHY | RN73C1J3K92BTDF | 3k92 | Resistor - 0.1% | Thin Film Chip Resistor | RESC1608X55N | R0603_3K92_0.1%_0.063W_10PPM
1.0 | R53 | GENERIC | R0603_7K87_0.1%_0.063W_10PPM | TYCO HOLSWORTHY | RN73C1J7K87BTDF | 7k87 | Resistor - 0.1% | Thin Film Chip Resistor | RESC1608X55N | R0603_7K87_0.1%_0.063W_10PPM
1.0 | R12 | GENERIC | R0603_21K_0.1%_0.063W_10PPM | TYCO HOLSWORTHY | RN73C1J21KBTDF | 21k | Resistor - 0.1% | Thin Film Chip Resistor | RESC1608X55N | R0603_21K_0.1%_0.063W_10PPM
1.0 | R52 | GENERIC | R0603_24K9_0.1%_0.063W_10PPM | TYCO HOLSWORTHY | RN73C1J24K9BTDF | 24k9 | Resistor - 0.1% | Thin Film Chip Resistor | RESC1608X55N | R0603_24K9_0.1%_0.063W_10PPM

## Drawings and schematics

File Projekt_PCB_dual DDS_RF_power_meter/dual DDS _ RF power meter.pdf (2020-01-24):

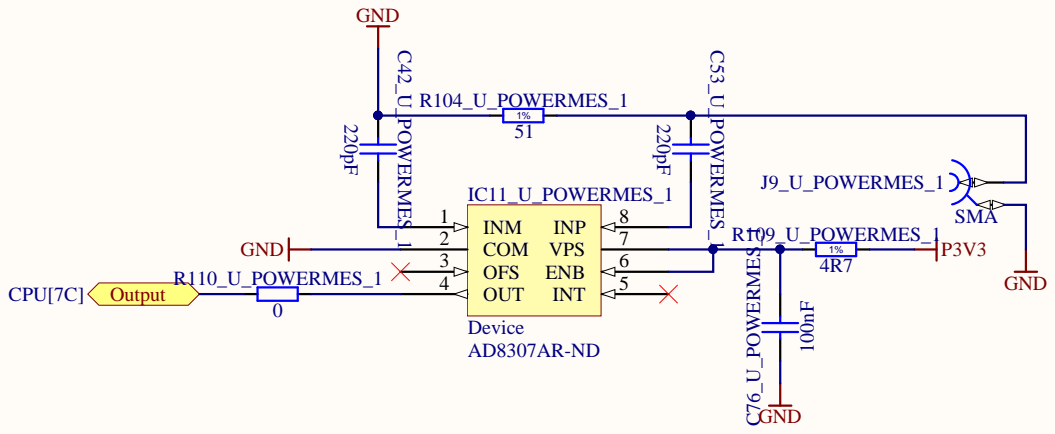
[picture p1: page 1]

OFS 3 | 1%

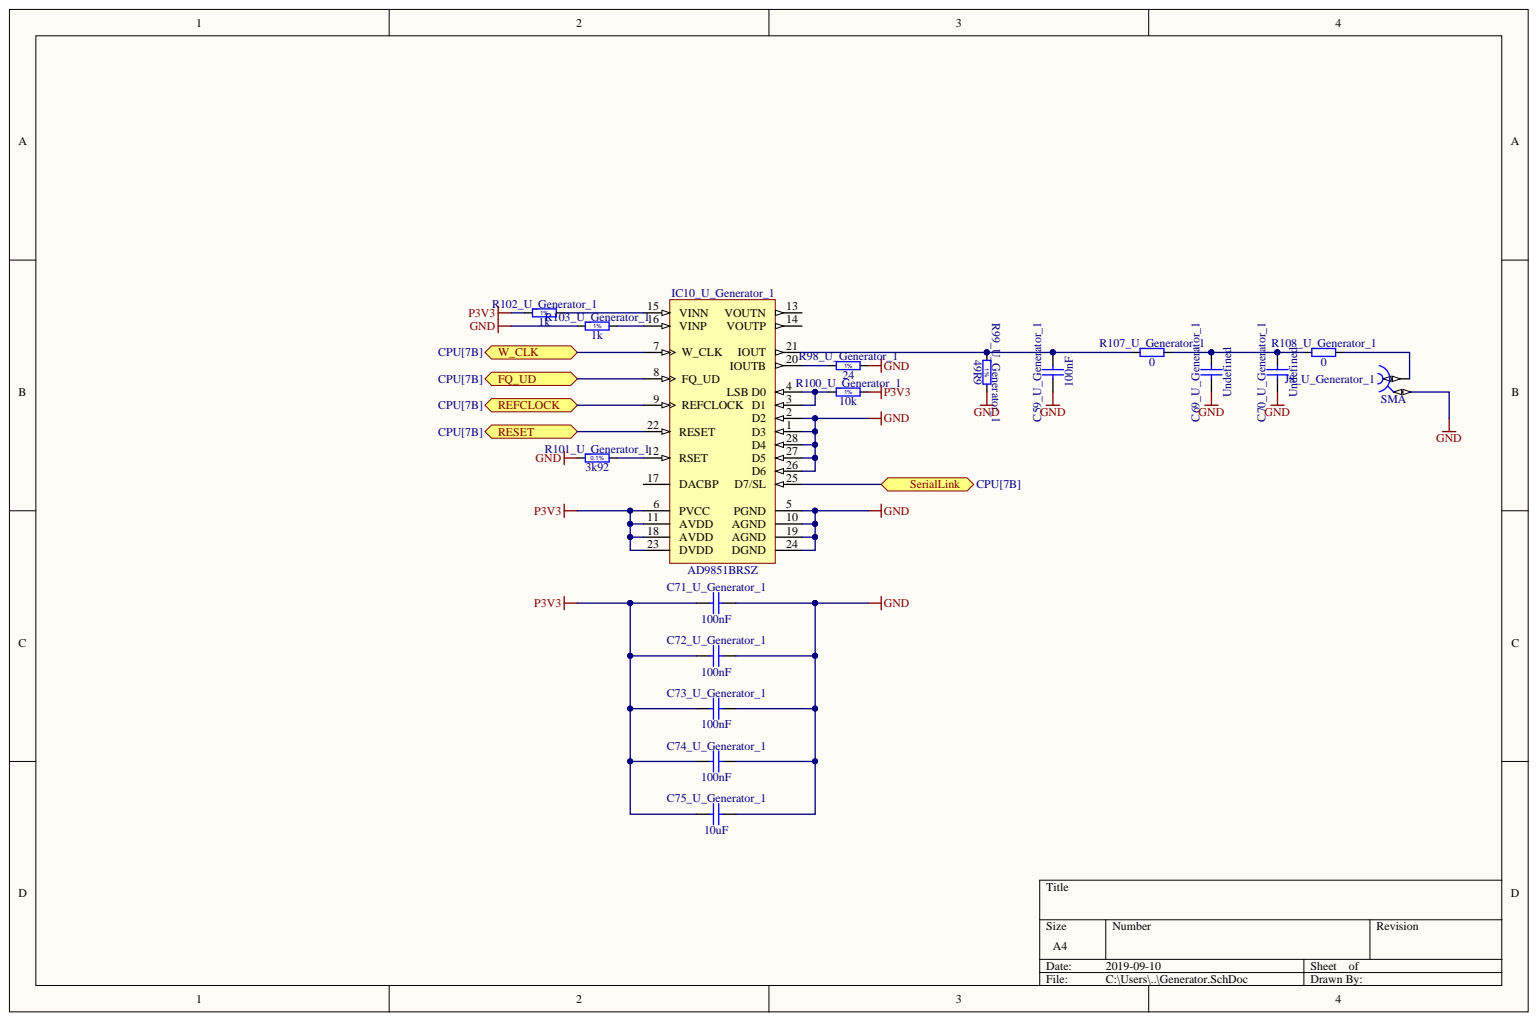
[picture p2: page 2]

1% R103_U_Generator_1 | VINP 16

1% | W_CLK 7 FQ_UD 8 REFCLOCK 9 RESET 22 RSET 12

0.1% | DACBP 17

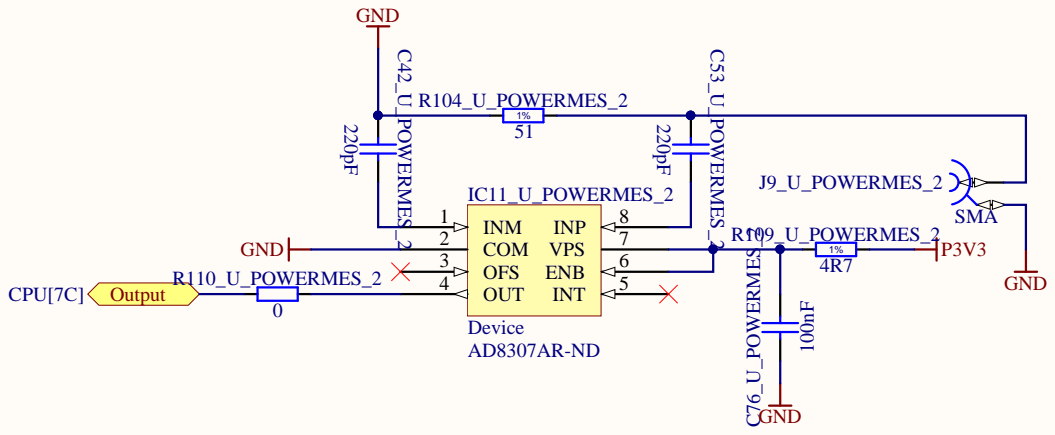
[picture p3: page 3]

OFS 3 | 1%

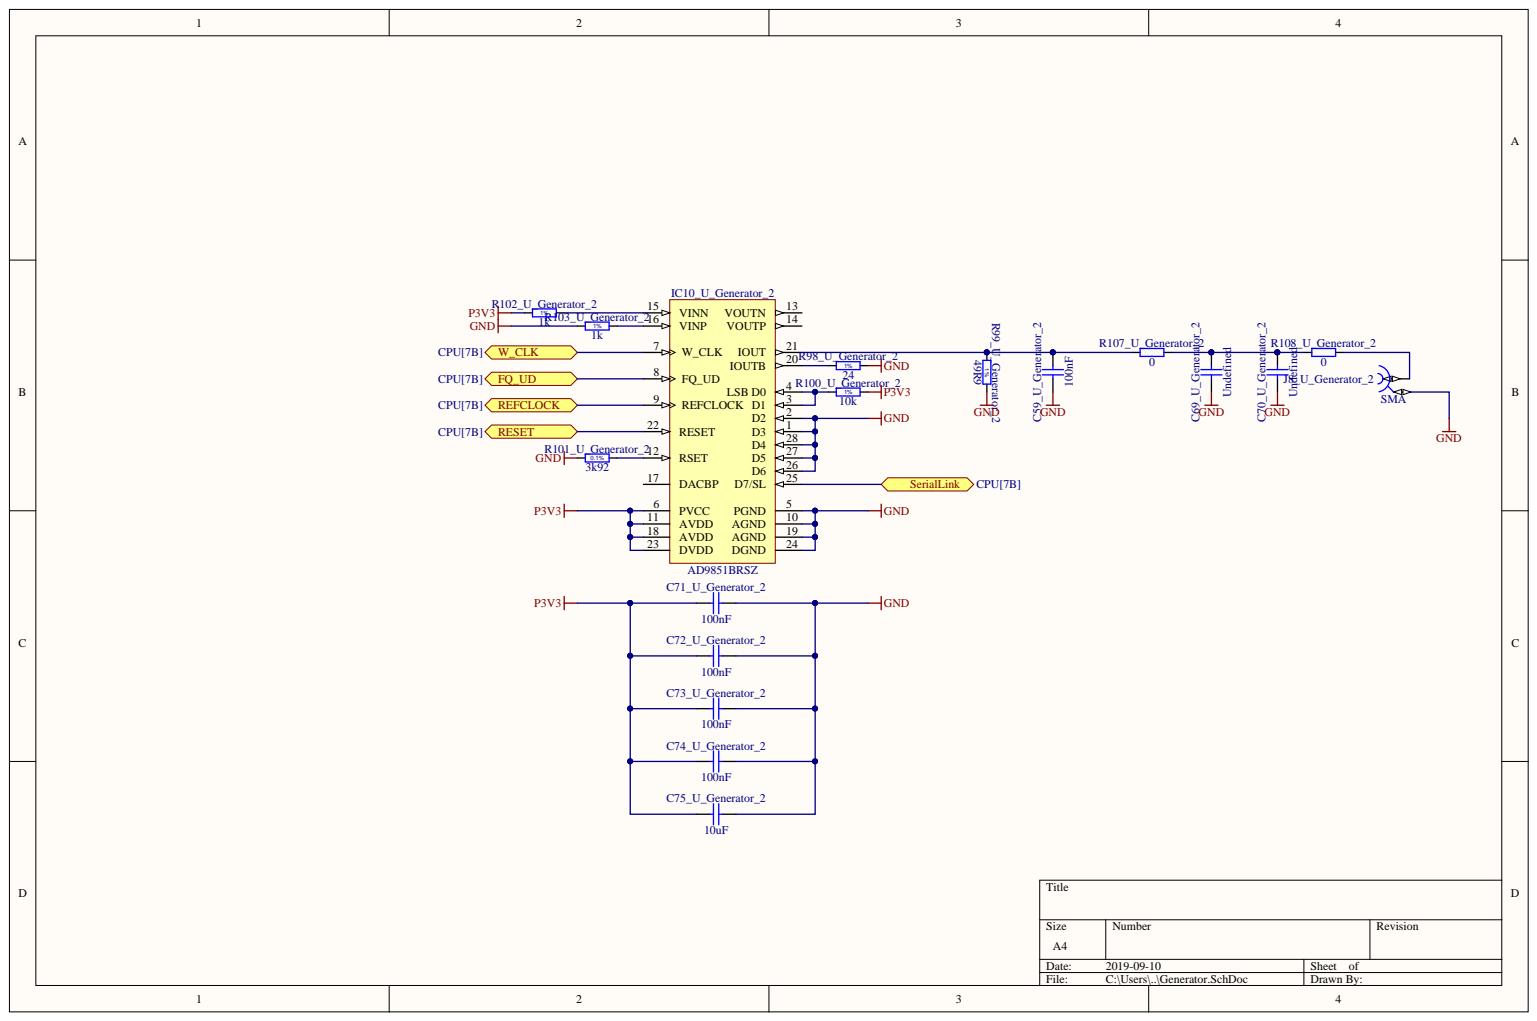
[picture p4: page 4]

1% R103_U_Generator_2 | VINP 16

1% | W_CLK 7 FQ_UD 8 REFCLOCK 9 RESET 22 RSET 12

0.1% | DACBP 17

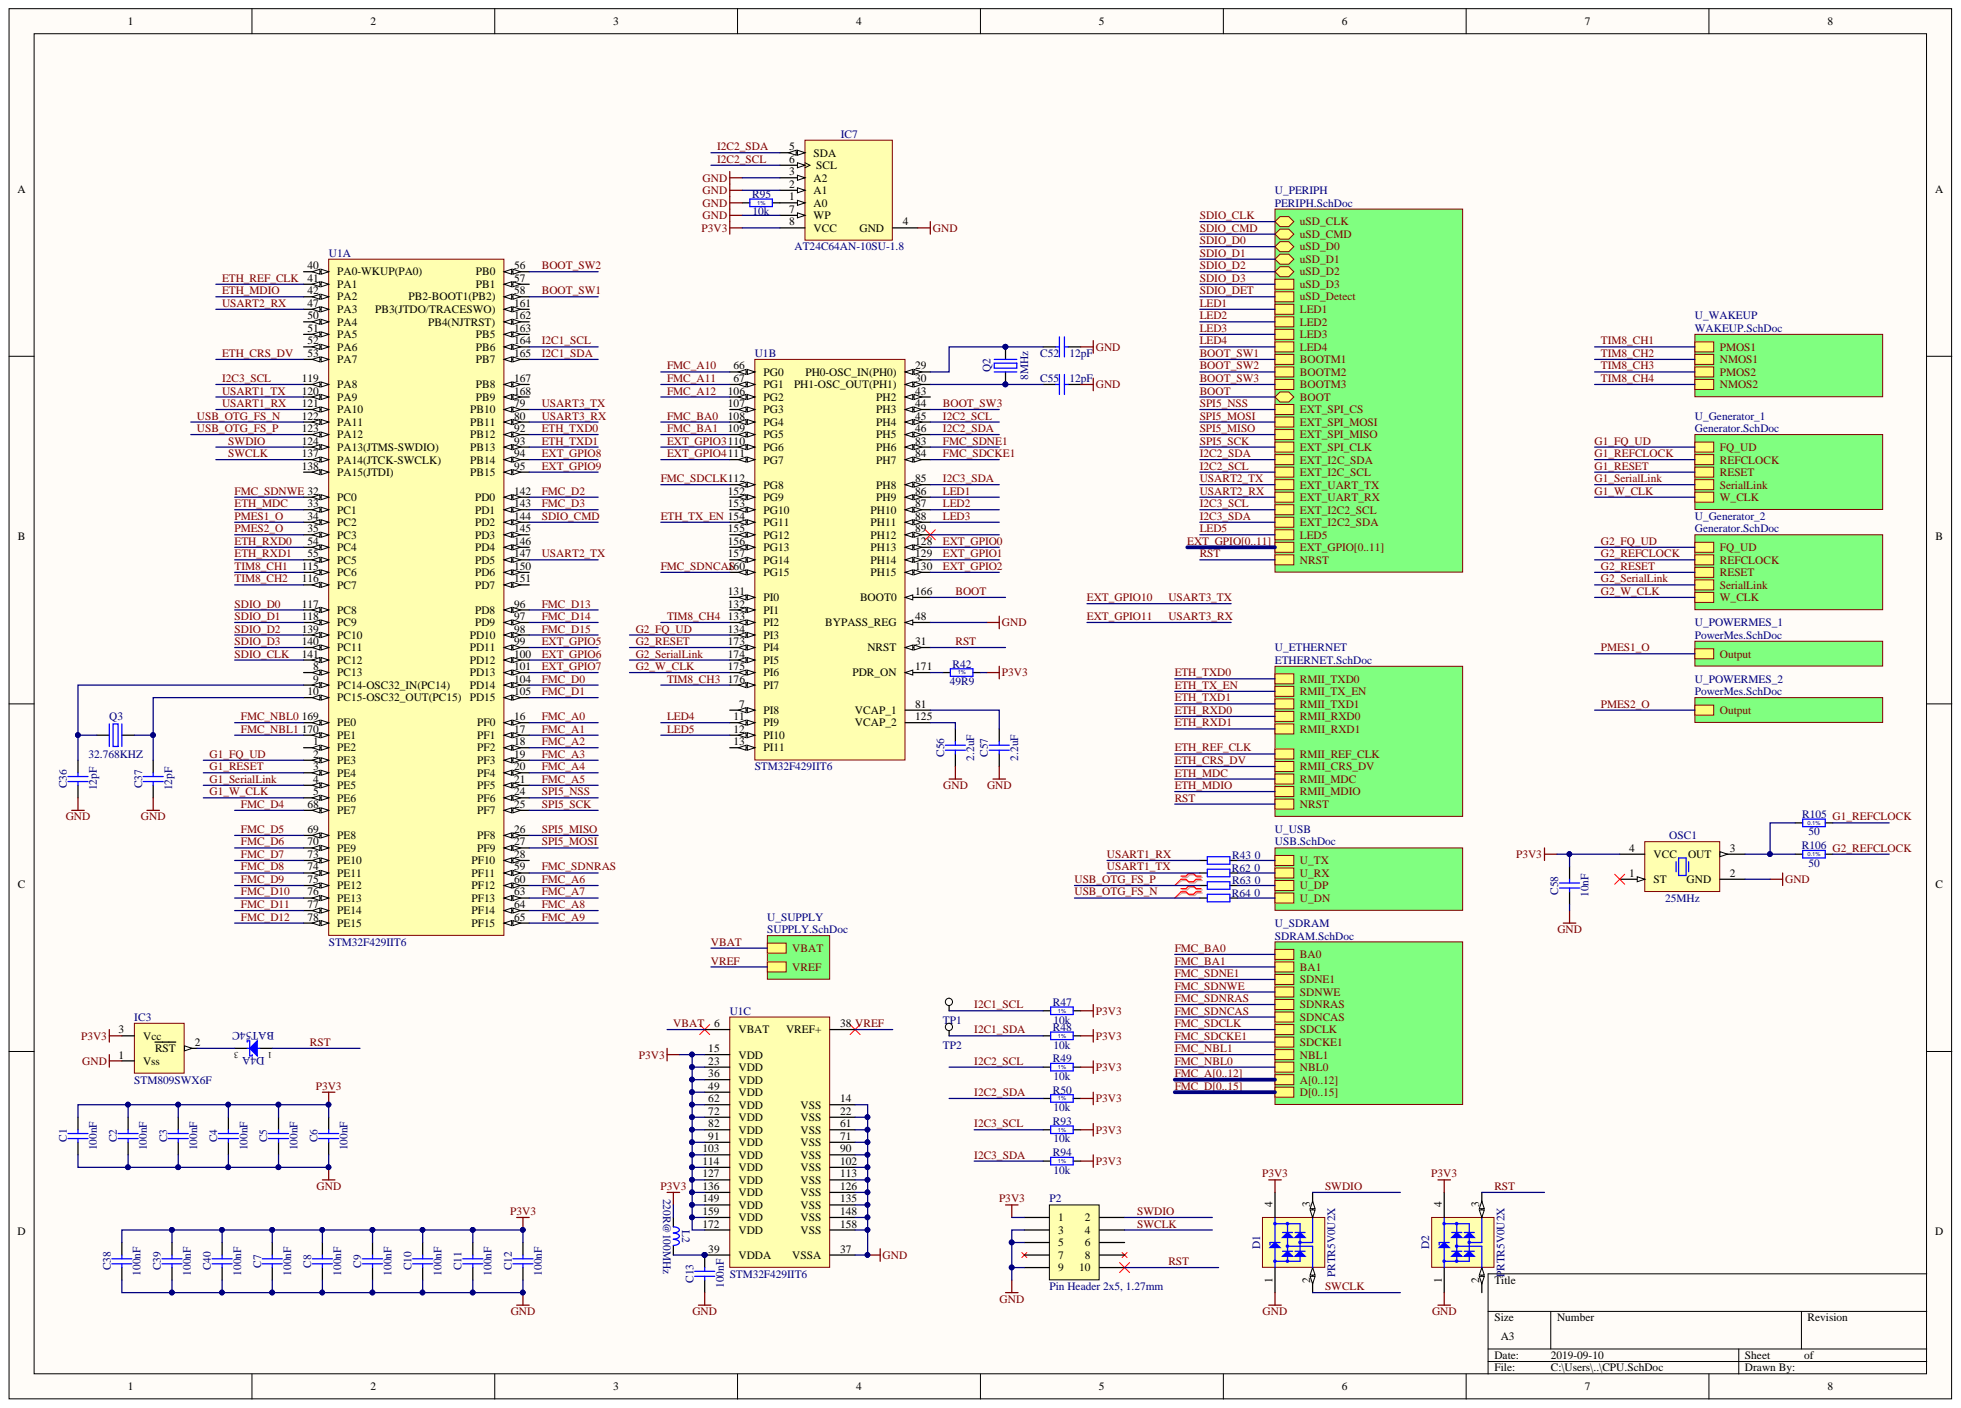
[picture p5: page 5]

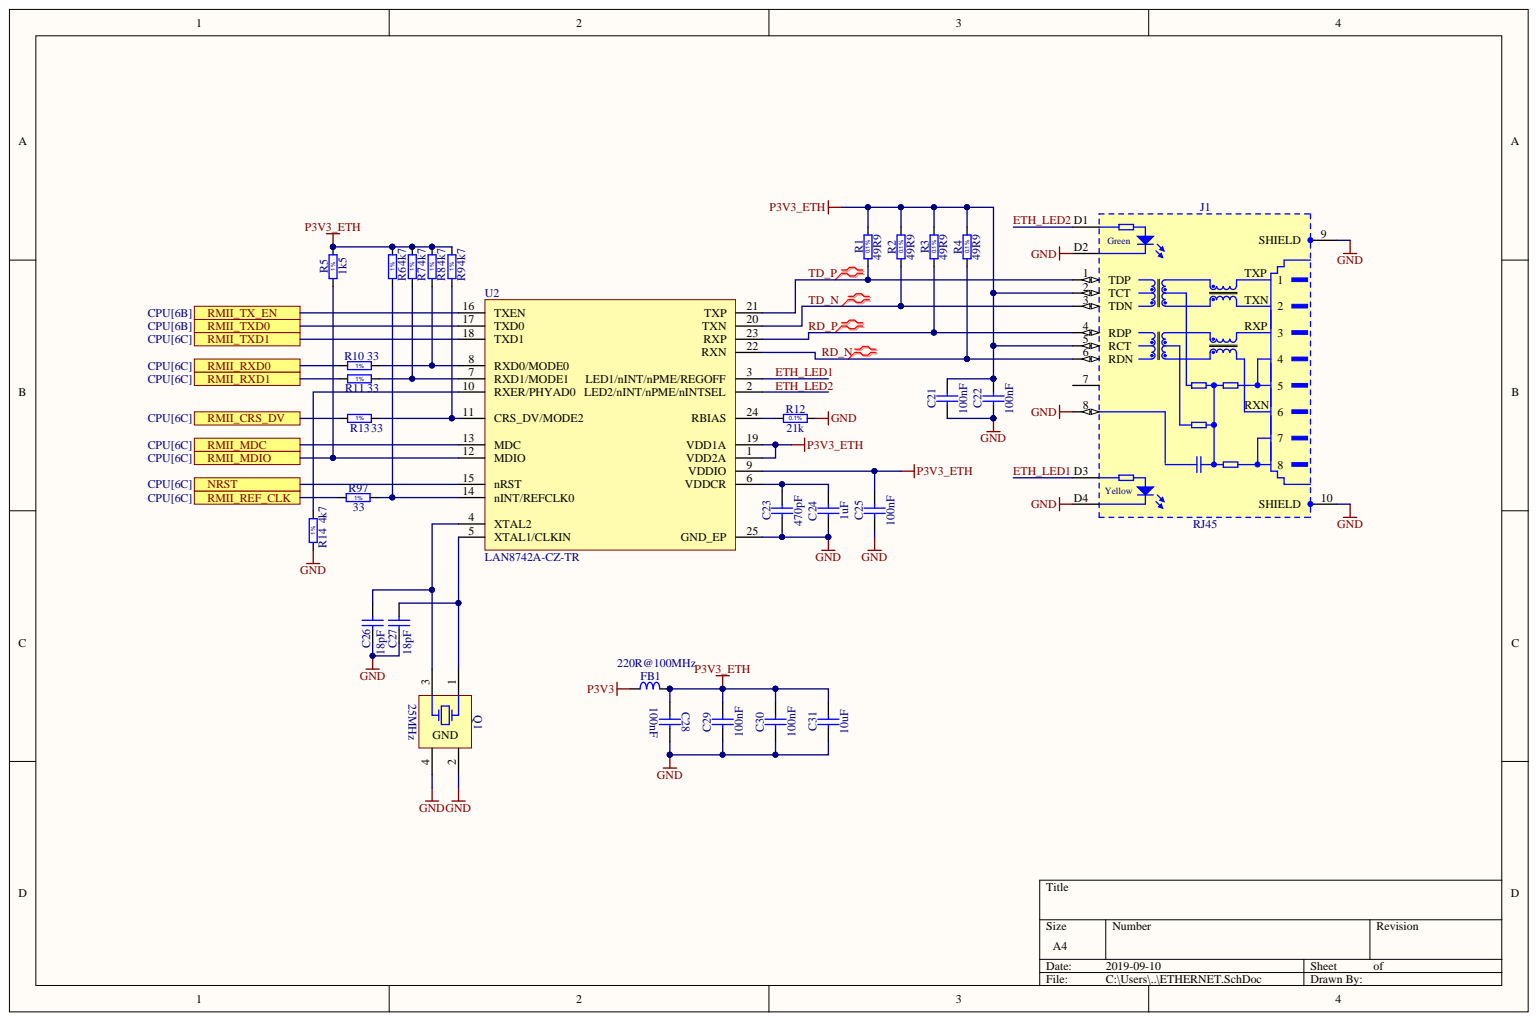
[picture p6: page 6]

TXD0 17

R10 33 | 7 | RXD0/MODE0 8 | RD_N
1% | | | ETH_LED1

CRS_DV/MODE2 11

R97 | nINT/REFCLK0 14

nRST 15

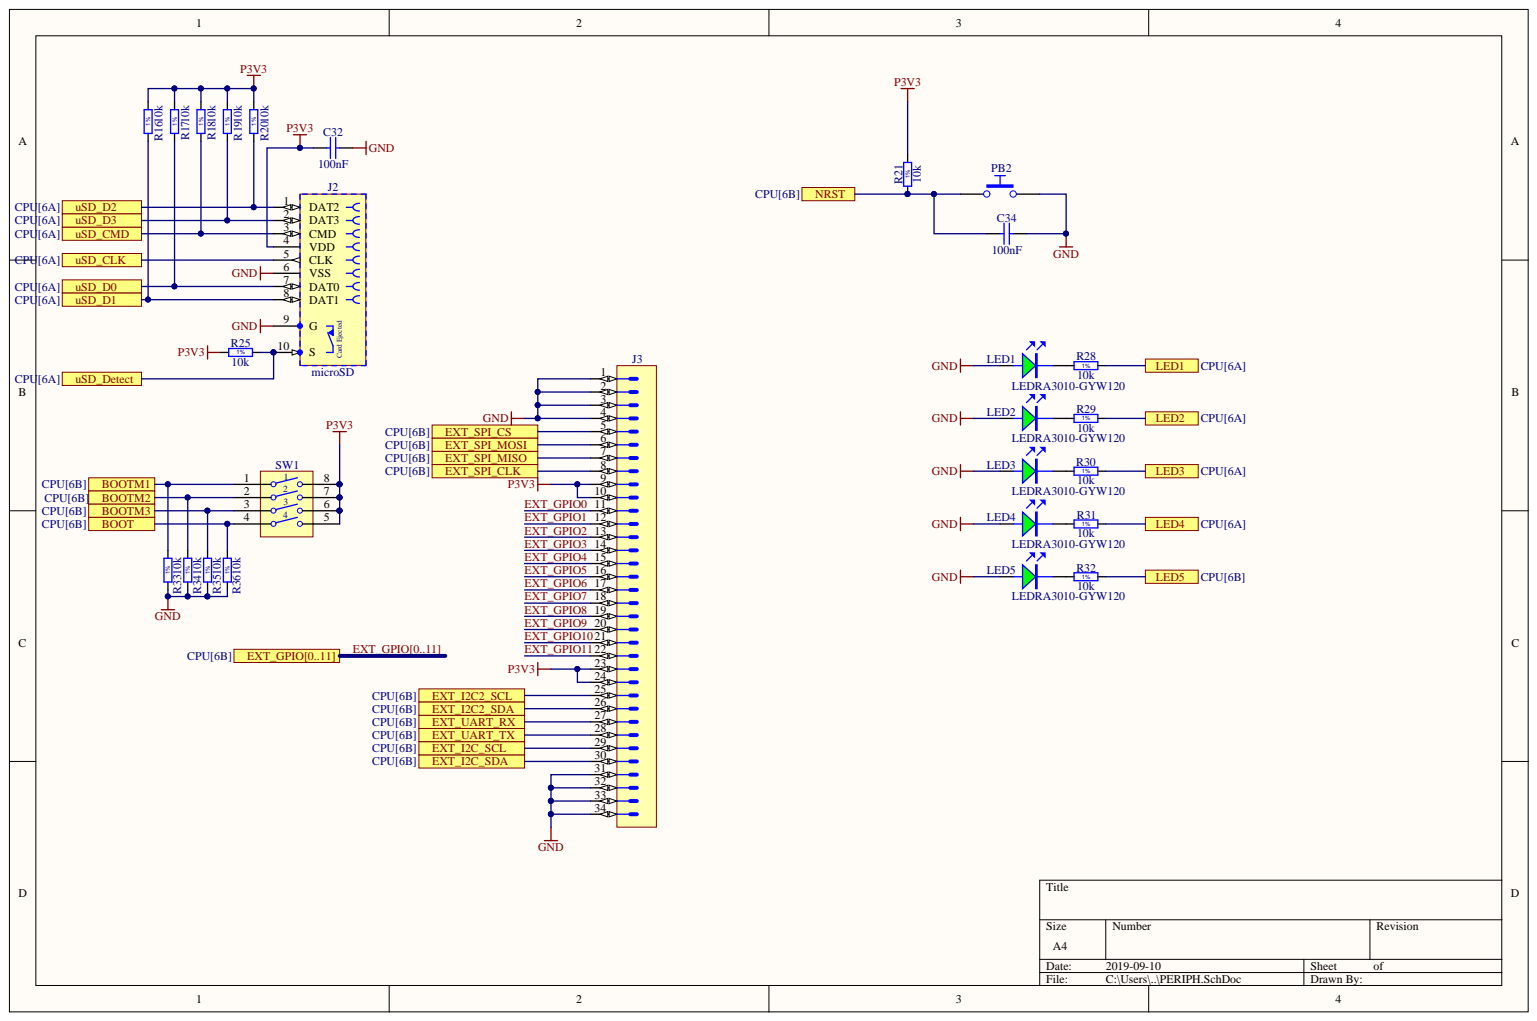
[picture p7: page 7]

DAT2 1
DAT3 2

VDD 4

VSS 6

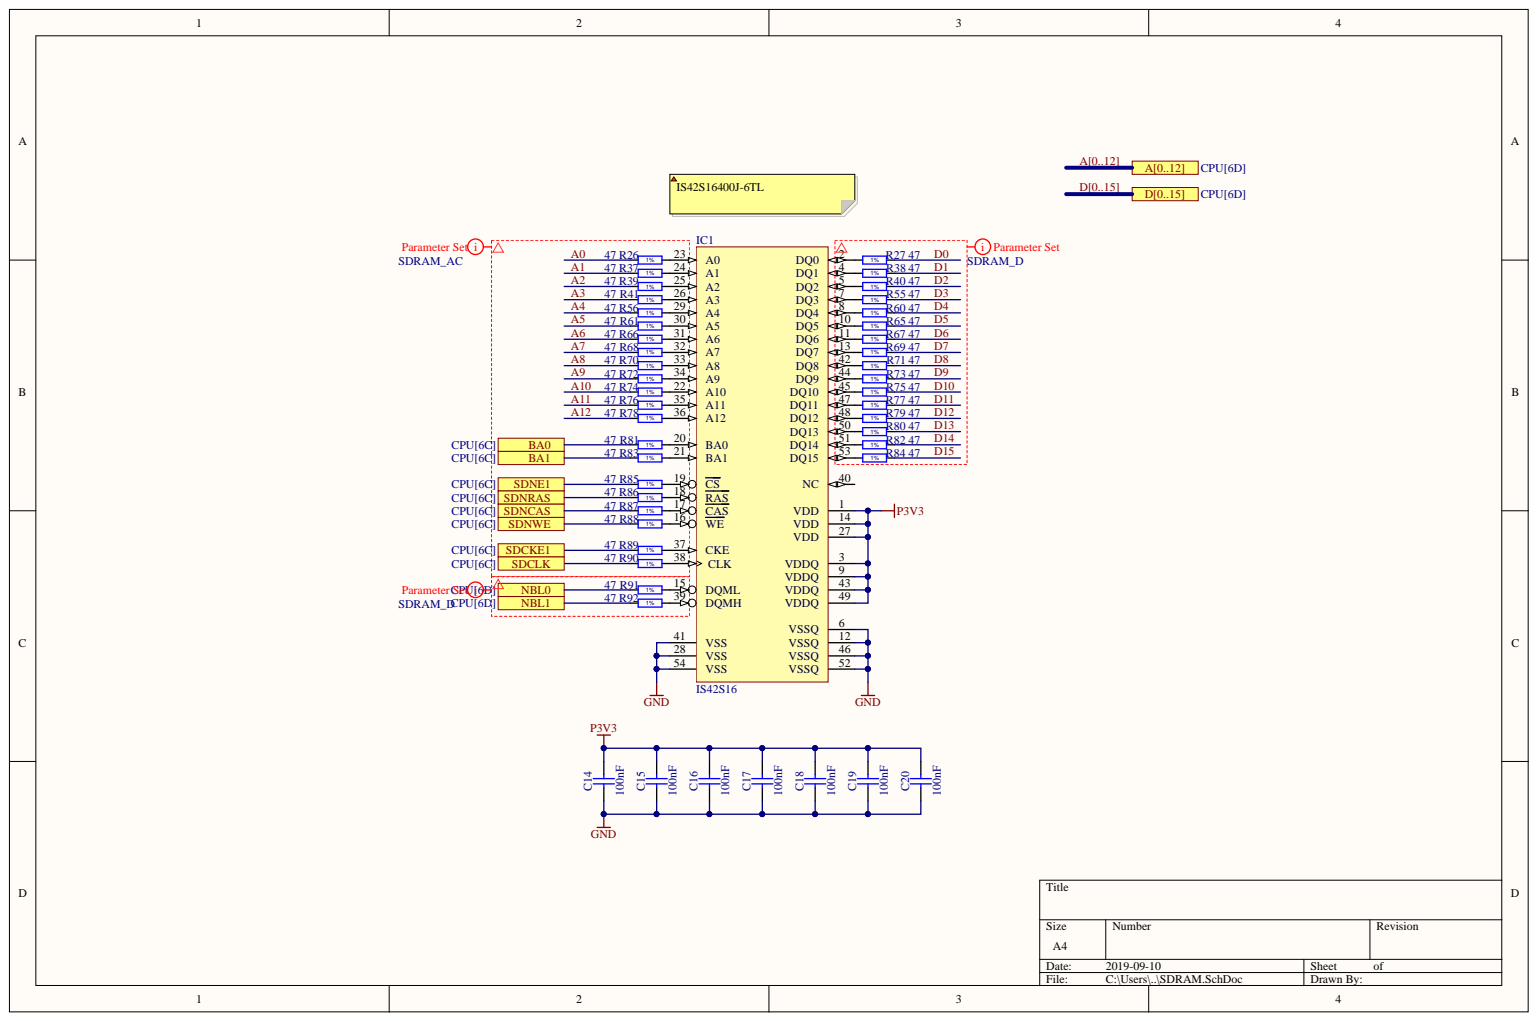
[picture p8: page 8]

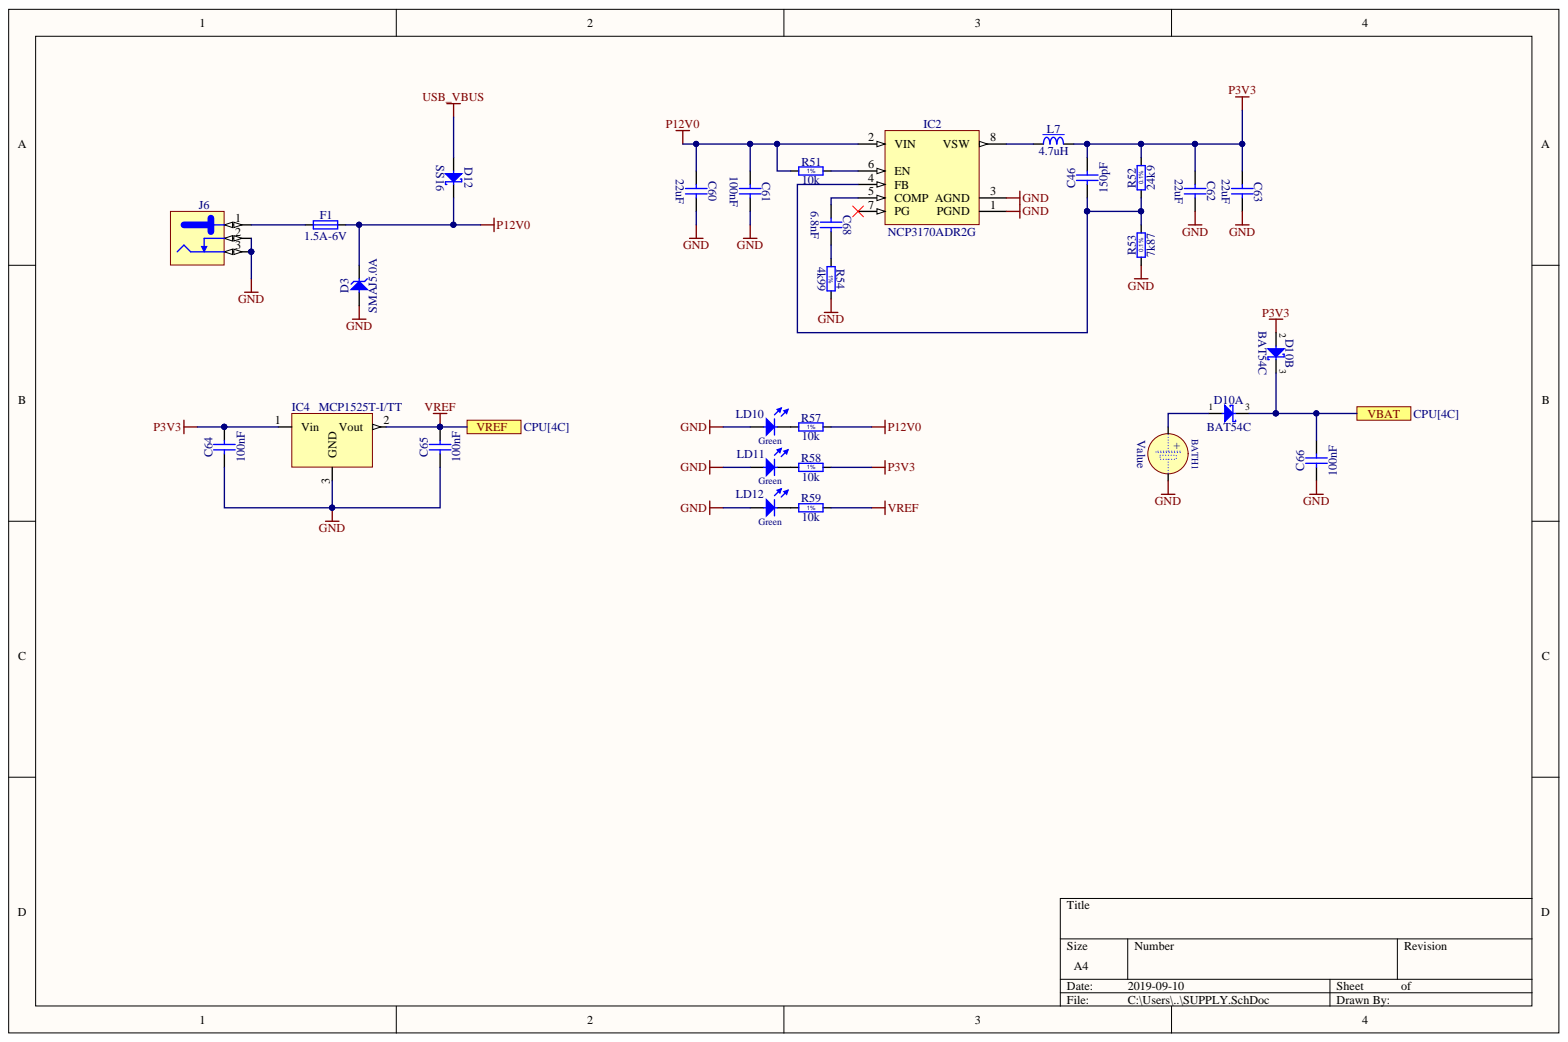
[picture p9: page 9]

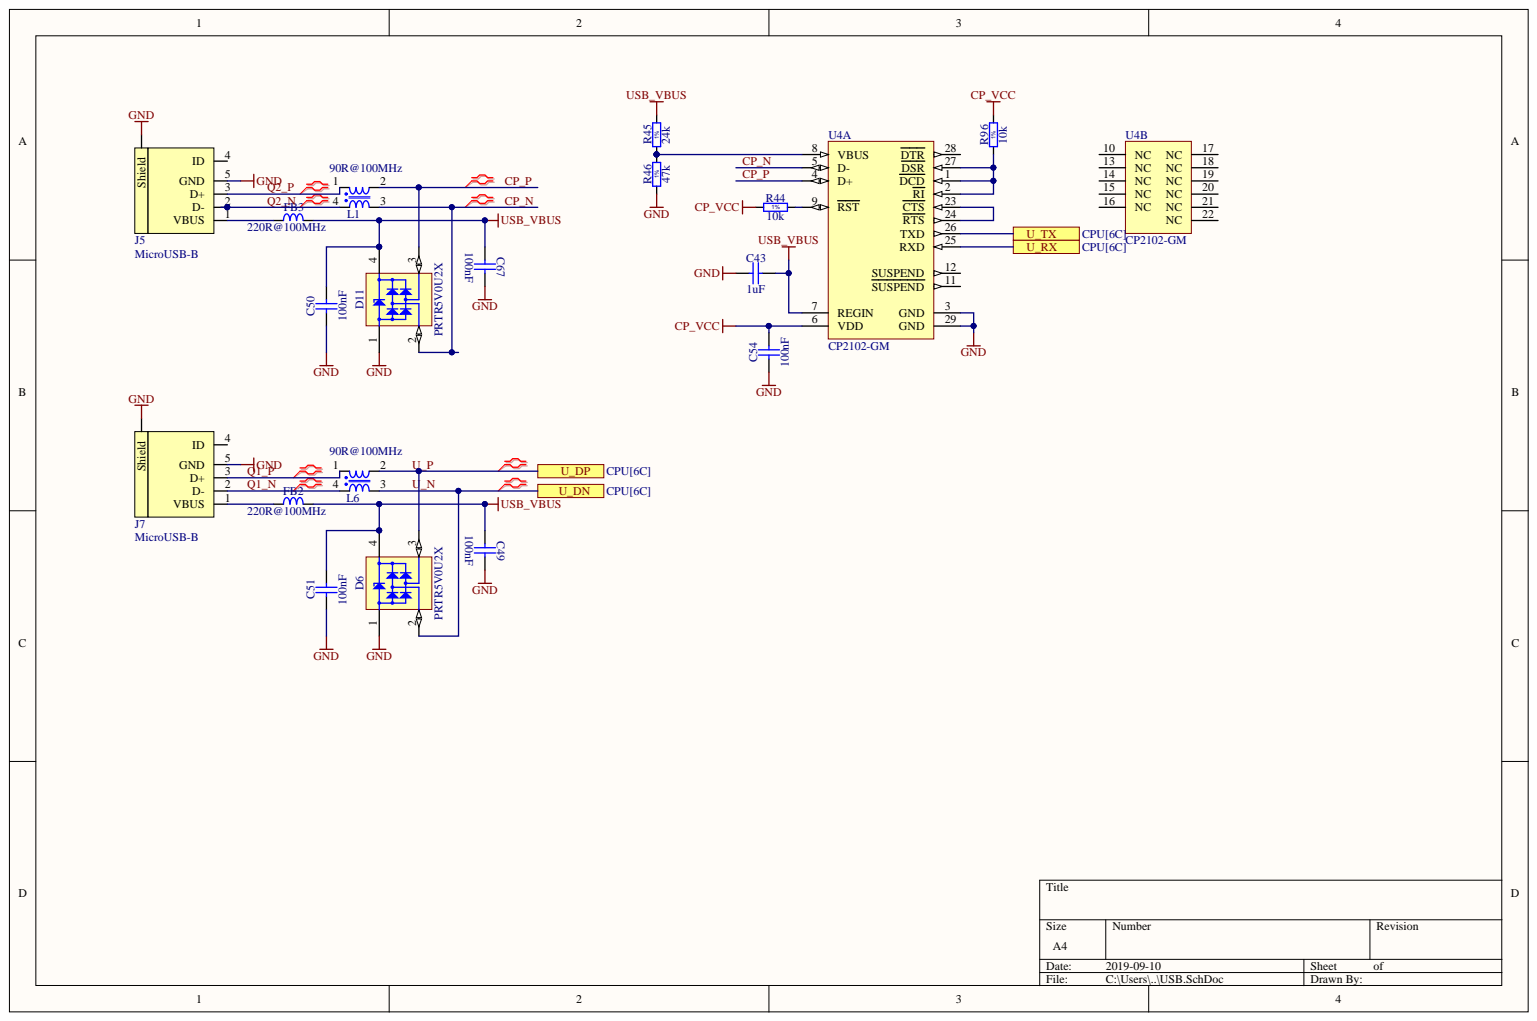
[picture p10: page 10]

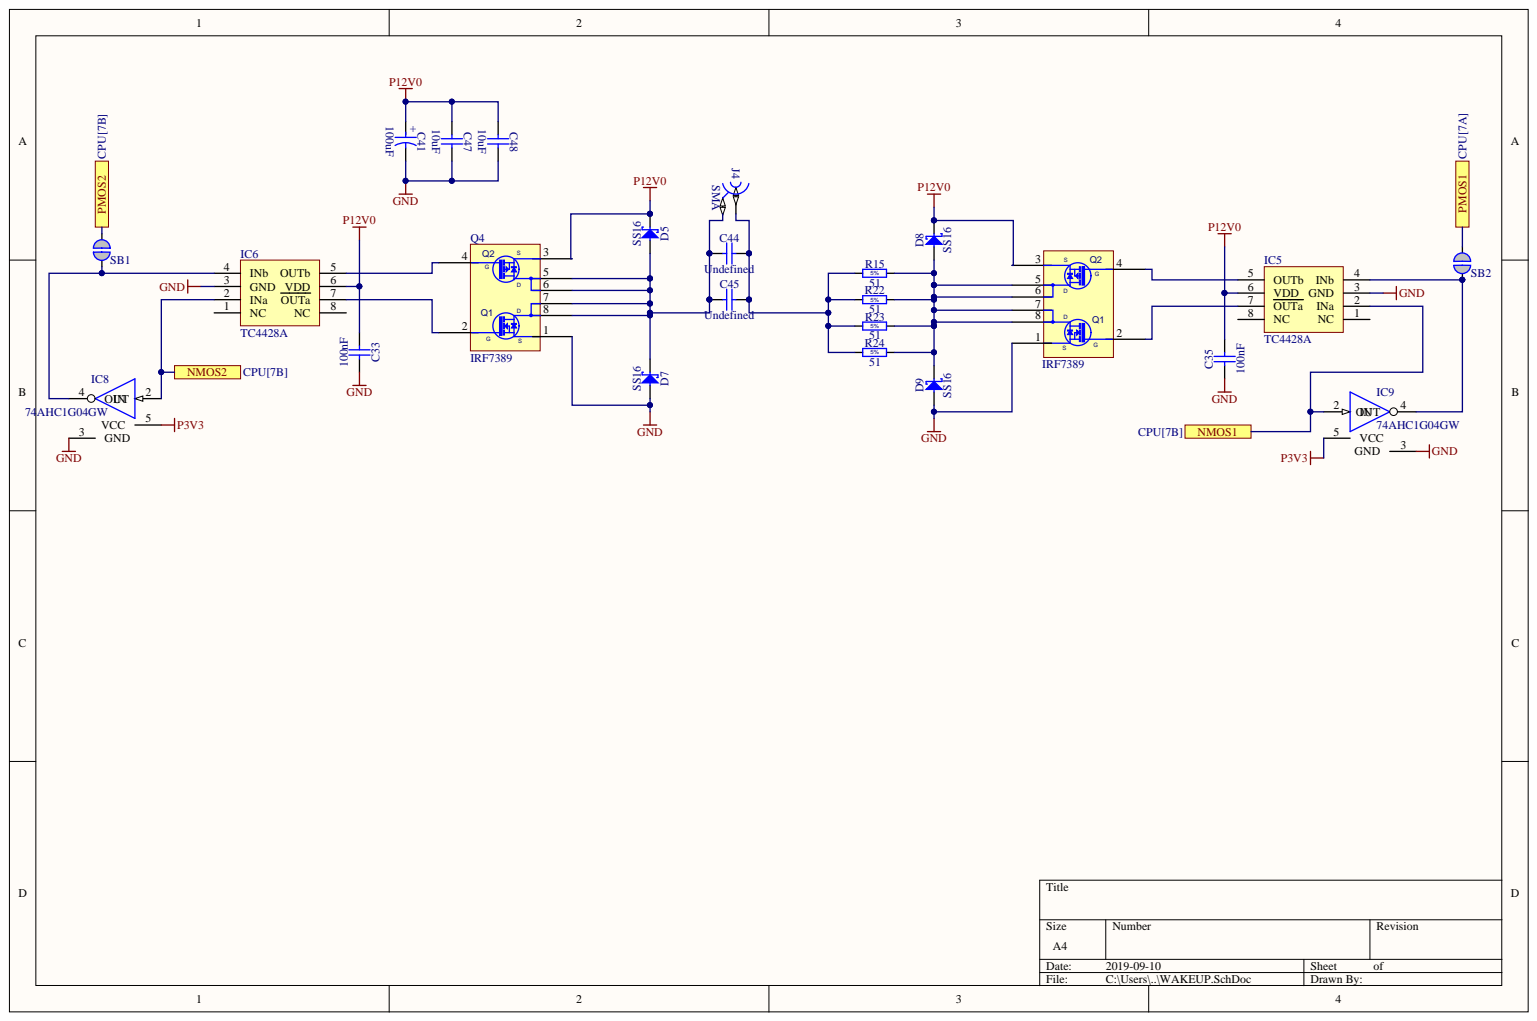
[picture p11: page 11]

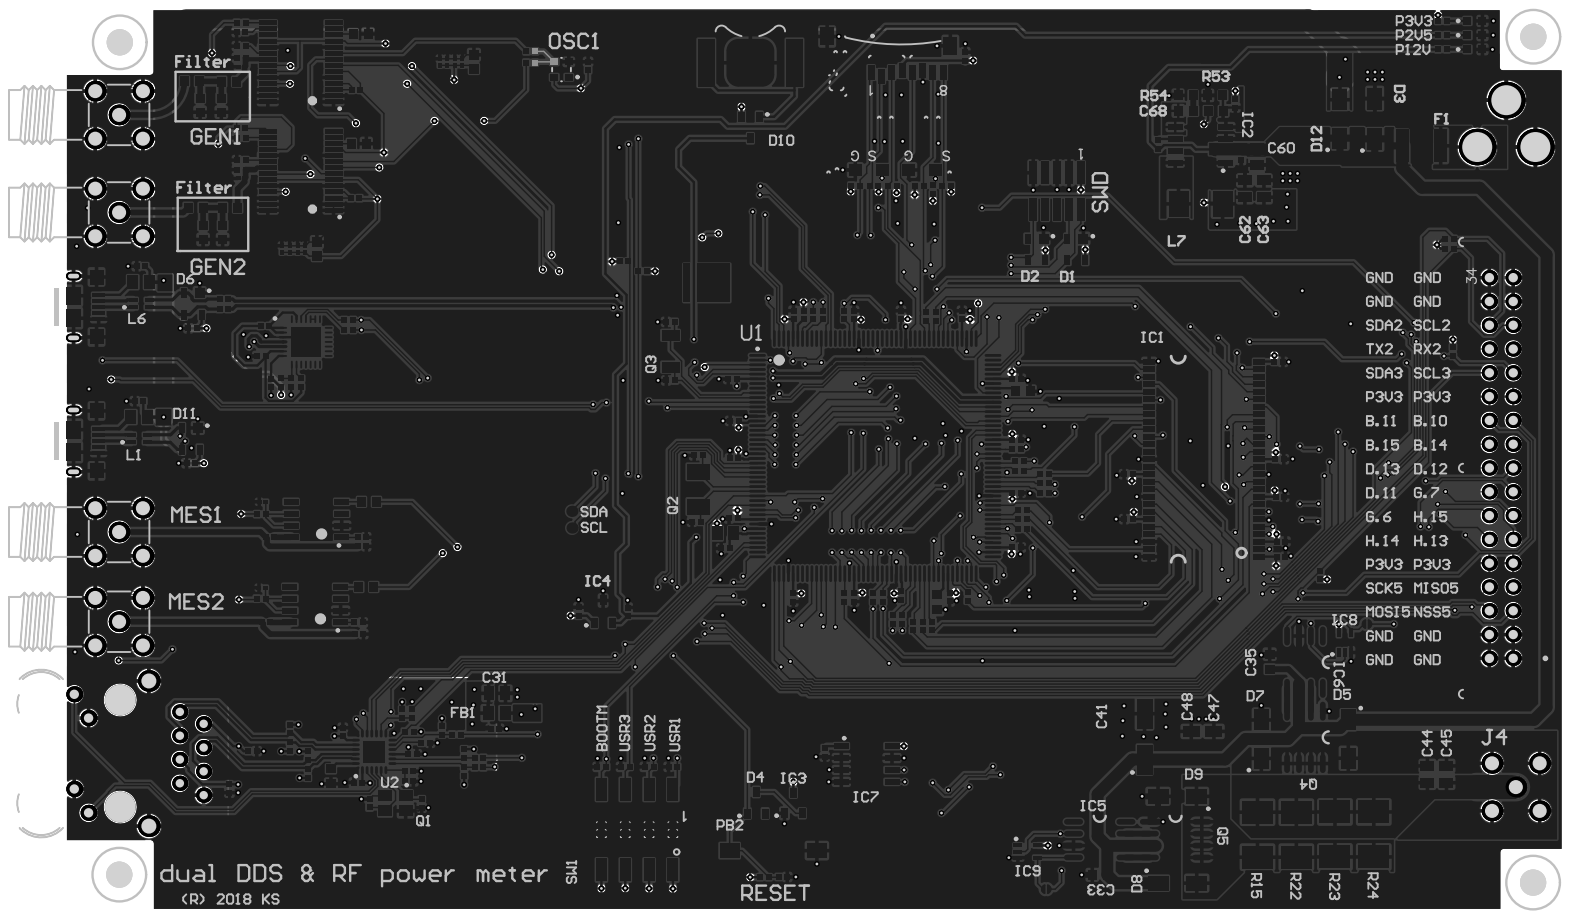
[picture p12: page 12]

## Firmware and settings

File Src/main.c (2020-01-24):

/**
  ******************************************************************************
  * @file           : main.c
  * @brief          : Main program body
  ******************************************************************************
  ** This notice applies to any and all portions of this file
  * that are not between comment pairs USER CODE BEGIN and
  * USER CODE END. Other portions of this file, whether 
  * inserted by the user or by software development tools
  * are owned by their respective copyright owners.
  *
  * COPYRIGHT(c) 2019 STMicroelectronics
  *
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
  ******************************************************************************
  */
/* Includes ------------------------------------------------------------------*/
#include "main.h"
#include "stm32f4xx_hal.h"

ADC_HandleTypeDef hadc1;

/* USER CODE BEGIN PV */
uint32_t PomiarADC;
uint32_t frik;
uint32_t aktualny;
uint32_t resultF;
uint32_t rfreq;
uint32_t VoPM;
/* USER CODE END PV */

void SystemClock_Config(void);
static void MX_GPIO_Init(void);
static void MX_ADC1_Init(void);

/* USER CODE BEGIN PFP */

/* USER CODE END PFP */

/**
  * @brief  The application entry point.
  *
  * @retval None
  */
int main(void)
{
  /* MCU Configuration----------------------------------------------------------*/

  /* Reset of all peripherals, Initializes the Flash interface and the Systick. */
  HAL_Init();

  /* Configure the system clock */
  SystemClock_Config();

  /* Initialize all configured peripherals */
  MX_GPIO_Init();
  MX_ADC1_Init();
  /* USER CODE BEGIN 2 */
  HAL_ADC_Start(&hadc1);

  //Begin of Serial initialization sequence

  HAL_GPIO_WritePin(CLK_GPIO_Port,CLK_Pin, GPIO_PIN_RESET);
  HAL_GPIO_WritePin(CLK_GPIO_Port,CLK_Pin, GPIO_PIN_SET);
  HAL_GPIO_WritePin(CLK_GPIO_Port,CLK_Pin, GPIO_PIN_RESET);
  HAL_GPIO_WritePin(FQ_UP_GPIO_Port,FQ_UP_Pin,GPIO_PIN_RESET);
  HAL_GPIO_WritePin(FQ_UP_GPIO_Port,FQ_UP_Pin,GPIO_PIN_SET);
  HAL_GPIO_WritePin(FQ_UP_GPIO_Port,FQ_UP_Pin,GPIO_PIN_RESET);

 firstiterationLV();

  /* USER CODE END 2 */

  /* Infinite loop */
  /* USER CODE BEGIN WHILE */
  while (1)
  {

	  if(rfreq<(26000000) || rfreq>(28000000))
	 	  {
	 		   firstiterationLV();
	 	  }

	 	  modulationLV2();

  /* USER CODE END WHILE */

  /* USER CODE BEGIN 3 */

  }
  /* USER CODE END 3 */

}

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
/* USER CODE BEGIN 4 */
void outOne() {
	HAL_GPIO_WritePin(CLK_GPIO_Port,CLK_Pin, GPIO_PIN_RESET);
	HAL_GPIO_WritePin(DATA_GPIO_Port, DATA_Pin, GPIO_PIN_SET);
	HAL_GPIO_WritePin(CLK_GPIO_Port,CLK_Pin, GPIO_PIN_SET);
	HAL_GPIO_WritePin(DATA_GPIO_Port, DATA_Pin, GPIO_PIN_RESET);

}
void outZero() {
	HAL_GPIO_WritePin(CLK_GPIO_Port,CLK_Pin, GPIO_PIN_RESET);
	HAL_GPIO_WritePin(DATA_GPIO_Port, DATA_Pin, GPIO_PIN_RESET);
	HAL_GPIO_WritePin(CLK_GPIO_Port,CLK_Pin, GPIO_PIN_SET);
}
void lastWord()
{
	//W0 = 00001001	last word		Final control byte, all 0x09 for 9851 chip
		outOne();
		outZero();
		outZero();
		outOne();
		outZero();
		outZero();
		outZero();
		outZero();
}

void sendFrequency(uint32_t frequency) {


	uint32_t freq =(frequency * 4294967295)/(150000000);

for(uint32_t i=0;i<32;i++)
		  {if (freq%2==1)
			  outOne();
		  else
			  outZero();
		        freq = freq >> 1;
		  }
lastWord();

   HAL_GPIO_WritePin(FQ_UP_GPIO_Port,FQ_UP_Pin,GPIO_PIN_SET);
   HAL_GPIO_WritePin(FQ_UP_GPIO_Port,FQ_UP_Pin,GPIO_PIN_RESET);
}
void MeasureADC(uint32_t iterations)
{
	for (uint32_t i=0; i<iterations ; i++)
	{
		if(HAL_ADC_PollForConversion(&hadc1, 10)==HAL_OK)
			{
				PomiarADC=PomiarADC+HAL_ADC_GetValue(&hadc1);
				HAL_ADC_Start(&hadc1);
			}
	} PomiarADC=PomiarADC/iterations;

}

//first iteration from 26,5MHz to 27,5MHz 	 accuracy 10kHz

void firstiterationLV()
{
	int beginF=25000000;
	int endF=29000000;
	int diffF=endF-beginF;
	int stepF=diffF/100;
	//int stepF=;
	int firstF=0, secondF=0;
	int lowest1V=4096,lowest2V=4097;
	int frequency=0;
	for(int i=0;i<100;i++)
	{
		frequency =stepF*i+beginF;//frequency =i*1000000;
		sendFrequency(frequency);
		MeasureADC(150);

	   if(lowest1V>PomiarADC)
	   {
		   secondF=firstF;
		   lowest2V=lowest1V;
		   firstF=frequency;
		   lowest1V=PomiarADC;
	   }
	   else if(lowest2V>PomiarADC)
	   {
		   secondF=frequency;
		   lowest2V=PomiarADC;
	   }
	}
	/***************************************************************
	 *
	 *
	 * 		Second iteration
	 * 		accuracy 10kHz
	 *
	 * *************************************************************/
		if(firstF<secondF)
		{
			beginF=firstF;
			endF=secondF;
		}
		else
		{
			endF=firstF;
			beginF=secondF;
		}
		diffF=endF-beginF;
		stepF=diffF/10;
		for(int j=0;j<10;j++)
			{
				frequency =stepF*j+beginF;
				sendFrequency(frequency);
				MeasureADC(15);

			   if(lowest1V>PomiarADC)
			   {
				   secondF=firstF;
				   lowest2V=lowest1V;
				   firstF=frequency;
				   lowest1V=PomiarADC;
			   }
			   else if(lowest2V>PomiarADC)
			   {
				   secondF=frequency;
				   lowest2V=PomiarADC;
			   }
			}

	/***************************************************************
	 *
	 *
	 * 		Third iteration
	 *		accuracy 100Hz
	 *
	 * *************************************************************/
		if(firstF<secondF)
		{
			beginF=firstF;
			endF=secondF;
		}
		else
		{
			endF=firstF;
			beginF=secondF;
		}
		diffF=endF-beginF;
		stepF=diffF/10;
		for(int j=0;j<10;j++)
			{
				frequency =stepF*j+beginF;
				sendFrequency(frequency);
				MeasureADC(15);

			   if(lowest1V>PomiarADC)
			   {
				   secondF=firstF;
				   lowest2V=lowest1V;
				   firstF=frequency;
				   lowest1V=PomiarADC;
			   }
			   else if(lowest2V>PomiarADC)
			   {
				   secondF=frequency;
				   lowest2V=PomiarADC;
			   }
			}

	sendFrequency(firstF);
	rfreq=firstF;
}

void modulationLV2()//Perturbation and observe method (P&O)
{
	uint32_t FStep=5000;//Hz
	MeasureADC(800);
	int test1F=rfreq-FStep;
	int test2F=rfreq+FStep;
	/*present freq*/
	VoPM=PomiarADC;

	/*test lower*/
	sendFrequency(test1F);
	MeasureADC(800);
	int lowerTestF_ADC=PomiarADC;
	/*test higher*/
	sendFrequency(test1F);
	MeasureADC(800);
	int higherTestF_ADC=PomiarADC;

	if(lowerTestF_ADC<VoPM)
	{
		rfreq=test1F;
	}
	else if(higherTestF_ADC<VoPM)
	{
		rfreq=test2F;
	}
	sendFrequency(rfreq);

}


/* USER CODE END 4 */
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


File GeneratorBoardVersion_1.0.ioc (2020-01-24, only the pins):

Mcu.UserName=STM32F429IITx
PC2.Signal=ADCx_IN12
PE3.GPIO_Label=FQ_UP
PE3.Signal=GPIO_Output
PE4.GPIO_Label=RST
PE4.Signal=GPIO_Output
PE5.GPIO_Label=DATA
PE5.Signal=GPIO_Output
PE6.GPIO_Label=CLK
PE6.Signal=GPIO_Output

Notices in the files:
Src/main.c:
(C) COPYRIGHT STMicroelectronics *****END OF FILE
